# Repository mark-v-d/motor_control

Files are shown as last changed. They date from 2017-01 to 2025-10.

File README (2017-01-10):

Work in progress.

Servo motor controller. Currently supporting Mitsubishi HC-PQ[23]4,
HC-MFS13 and motors with a Hiperface encoder. Communication with ethernet
and the controller is intended to be used with linuxcnc.

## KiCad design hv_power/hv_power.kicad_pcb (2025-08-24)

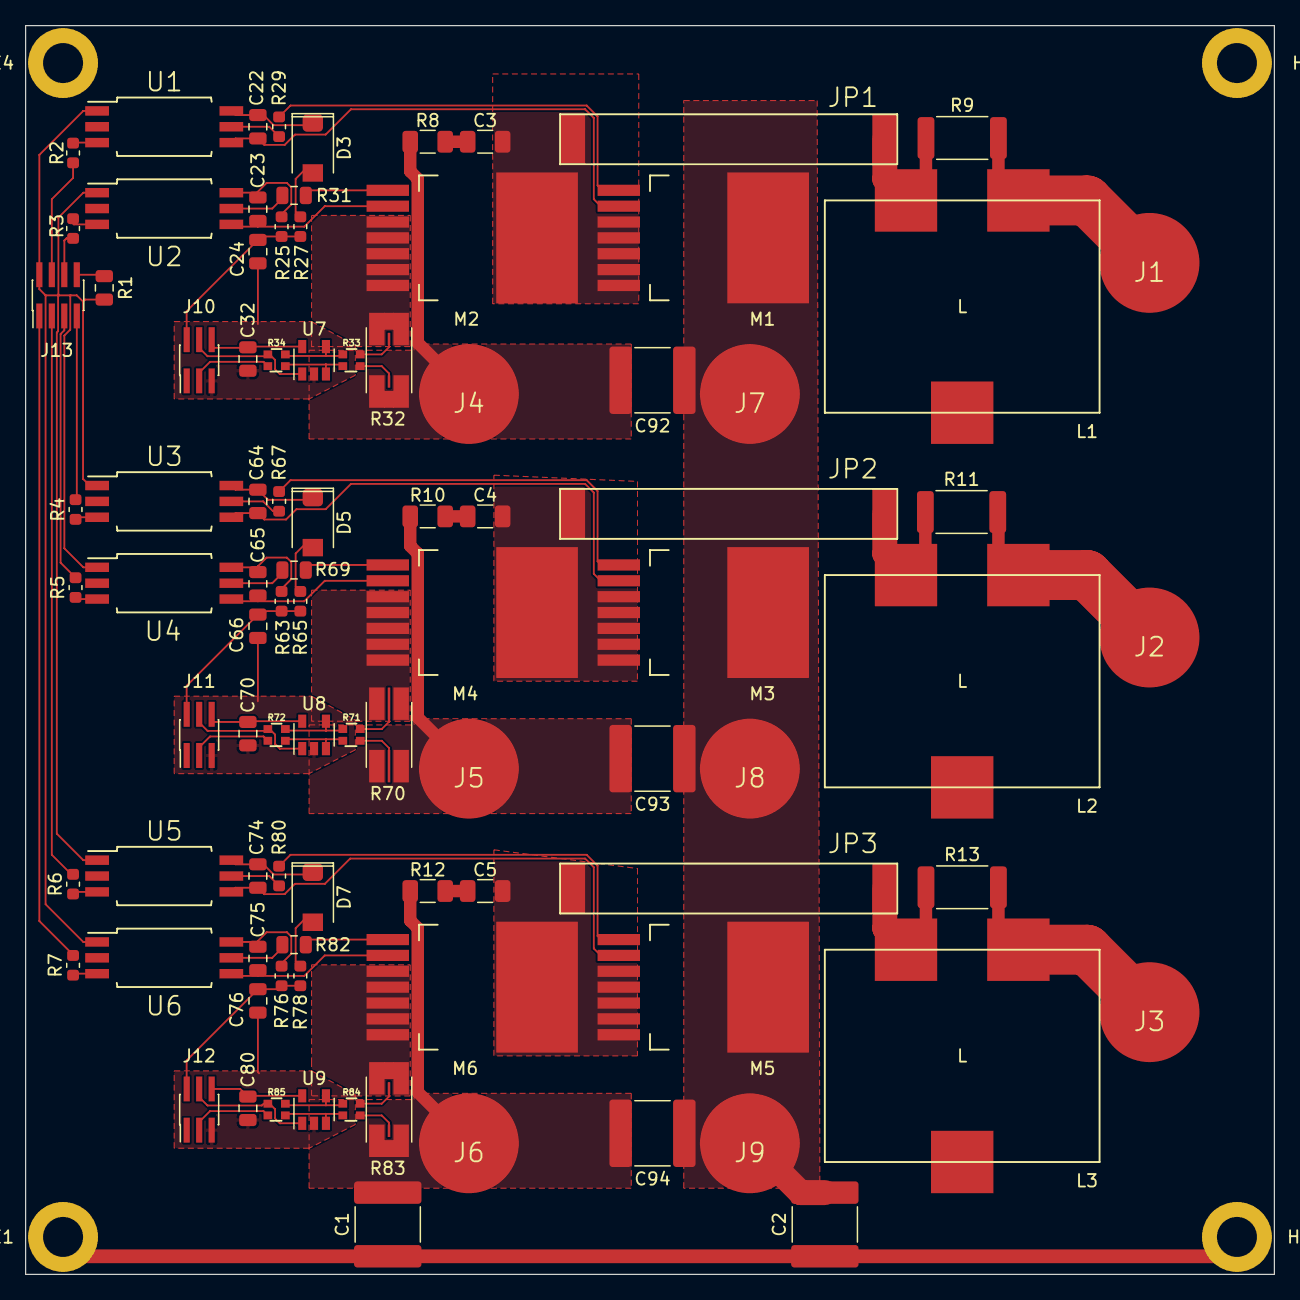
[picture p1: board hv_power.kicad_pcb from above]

Board: 2 copper layers, 100.0 x 100.0 mm, 95 parts (0 on the bottom side), 88 nets.

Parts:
C1, C2: 3.3nF; C_2220_5650Metric
C3, C4, C5: C; C_1206_3216Metric
C22, C23, C24, C64, C65, C66, C74, C75, C76: 1uF; C_0805_2012Metric
C32, C70, C80: 100nF; C_0805_2012Metric
C92, C93, C94: 100nF; C_2220_5650Metric
D3, D5, D7: STTH112A; D_SMA
HOLE1, HOLE4: HOLE; MountingHole_3.2mm_M3_DIN965_Pad
HOLE2, HOLE3: HOLE; MountingHole_3.2mm_M3_DIN965_Pad_ScreenAlignment
J1, J2, J3: Conn_01x01_Male; Wurth_7466204
J4, J5, J6: V-; Wurth_7466204
J7, J8, J9: V+; Wurth_7466204
J10, J11, J12: Conn_02x03_Odd_Even; PinHeader_2x03_P1.00mm_Vertical_SMD
J13: Conn_02x04_Odd_Even; PinHeader_2x04_P1.00mm_Vertical_SMD
JP1, JP2, JP3: Jumper_2_Bridged; jumper_3x25mm
L1, L2, L3: L; WE-HCF2013
M1, M2, M3, M4, M5, M6: TBD; TO-263-7-GDSKS_novias
R1: NTC; R_0805_2012Metric
R2, R3, R4, R5, R6, R7: 270; R_0603_1608Metric
R8, R10, R12: R; R_1206_3216Metric
R9, R11, R13: 270; R_2512_6332Metric
R25, R27, R29, R63, R65, R67, R76, R78, R80: 4.7; R_0603_1608Metric
R31, R69, R82: 4.7; R_0805_2012Metric
R32, R70, R83: R_Shunt; R_2512_Shunt_Rohm_PMR100_3.0m
R33, R71, R84: 100; ACASN
R34, R72, R85: 2k; ACASN
U1, U2, U3, U4, U5, U6: UCC23511DWY; SOIC-6_7.5x4.68mm_P1.27mm
U7, U8, U9: TSV991ILT; SOT-23-5

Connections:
+3.3V: J13.2, R1.1, U1.1 (anode), U2.1 (anode), U3.1 (anode), U4.1 (anode), U5.1 (anode), U6.1 (anode)
+800V: C2.2, C92.1, C93.1, C94.1, J7.1, J8.1, J9.1, M1.D, M3.D, M5.D
/HBH0: J13.4, R2.2
/HBH1: J13.7, R4.2
/HBH2: J13.3, R6.2
/HBL0: J13.6, R3.2
/HBL1: J13.5, R5.2
/HBL2: J13.1, R7.2
/H_Bridge0/0: C24.1, C32.2, J10.5, U7.2 (V-)
/H_Bridge0/+3.3: C32.1, J10.6, U7.5 (V+)
/H_Bridge0/+12: C24.2, J10.2, R25.2, R27.1
/H_Bridge0/CS: M2.S, R32.1
/H_Bridge0/C_N: J10.4, R34.1, U7.1
/H_Bridge0/C_P: J10.3, R34.2
/H_Bridge0/I_N: R33.1, R34.4, U7.4 (-)
/H_Bridge0/I_P: R33.2, R34.3, U7.3 (+)
/H_Bridge0/V-: C92.2, J4.1, R8.2, R32.4
/H_Bridge0/d1: R2.1, U1.3 (cathode)
/H_Bridge0/d2: R3.1, U2.3 (cathode)
/H_Bridge0/sw: C3.1, JP1.1 (A), M1.S, M2.D
/H_Bridge0/sw_+: C22.1, D3.C, U1.6 (vcc)
/H_Bridge0/sw_g: M1.G, R29.1
/H_Bridge0/sw_m1: JP1.2 (B), L1.2, R9.1
/H_Bridge0/sw_m2: J1.1, L1.1, R9.2
/H_Bridge0/sw_o: R29.2, U1.5 (out)
/H_Bridge0/sw_s: C22.2, M1.KS (ks), U1.4 (gnd)
/H_Bridge0/x: C3.2, R8.1
/H_Bridge1/0: C66.1, C70.2, J11.5, U8.2 (V-)
/H_Bridge1/+3.3: C70.1, J11.6, U8.5 (V+)
/H_Bridge1/+12: C66.2, J11.2, R63.2, R65.1
/H_Bridge1/CS: M4.S, R70.1
/H_Bridge1/C_N: J11.4, R72.1, U8.1
/H_Bridge1/C_P: J11.3, R72.2
/H_Bridge1/I_N: R71.1, R72.4, U8.4 (-)
/H_Bridge1/I_P: R71.2, R72.3, U8.3 (+)
/H_Bridge1/V-: C93.2, J5.1, R10.2, R70.4
/H_Bridge1/d1: R4.1, U3.3 (cathode)
/H_Bridge1/d2: R5.1, U4.3 (cathode)
/H_Bridge1/sw: C4.1, JP2.1 (A), M3.S, M4.D
/H_Bridge1/sw_+: C64.1, D5.C, U3.6 (vcc)
/H_Bridge1/sw_g: M3.G, R67.1
/H_Bridge1/sw_m1: JP2.2 (B), L2.2, R11.1
/H_Bridge1/sw_m2: J2.1, L2.1, R11.2
/H_Bridge1/sw_o: R67.2, U3.5 (out)
/H_Bridge1/sw_s: C64.2, M3.KS (ks), U3.4 (gnd)
/H_Bridge1/x: C4.2, R10.1
/H_Bridge2/0: C76.1, C80.2, J12.5, U9.2 (V-)
/H_Bridge2/+3.3: C80.1, J12.6, U9.5 (V+)
/H_Bridge2/+12: C76.2, J12.2, R76.2, R78.1
/H_Bridge2/CS: M6.S, R83.1
/H_Bridge2/C_N: J12.4, R85.1, U9.1
/H_Bridge2/C_P: J12.3, R85.2
/H_Bridge2/I_N: R84.1, R85.4, U9.4 (-)
/H_Bridge2/I_P: R84.2, R85.3, U9.3 (+)
/H_Bridge2/V-: C1.2, C94.2, J6.1, R12.2, R83.4
/H_Bridge2/d1: R6.1, U5.3 (cathode)
/H_Bridge2/d2: R7.1, U6.3 (cathode)
/H_Bridge2/sw: C5.1, JP3.1 (A), M5.S, M6.D
/H_Bridge2/sw_+: C74.1, D7.C, U5.6 (vcc)
/H_Bridge2/sw_g: M5.G, R80.1
/H_Bridge2/sw_m1: JP3.2 (B), L3.2, R13.1
/H_Bridge2/sw_m2: J3.1, L3.1, R13.2
/H_Bridge2/sw_o: R80.2, U5.5 (out)
/H_Bridge2/sw_s: C74.2, M5.KS (ks), U5.4 (gnd)
/H_Bridge2/x: C5.2, R12.1
/ntc: J13.8, R1.2
/pe: C1.1, C2.1, HOLE1.1, HOLE2.1
unnamed: D3.A, R27.2
unnamed: D5.A, R65.2
unnamed: D7.A, R78.2
unnamed: M2.G, R31.1
unnamed: C23.2, M2.KS (ks), U2.4 (gnd)
unnamed: M4.G, R69.1
unnamed: C65.2, M4.KS (ks), U4.4 (gnd)
unnamed: M6.G, R82.1
unnamed: C75.2, M6.KS (ks), U6.4 (gnd)
unnamed: R32.2, R33.4
unnamed: R32.3, R33.3
unnamed: R70.2, R71.4
unnamed: R70.3, R71.3
unnamed: R83.2, R84.4
unnamed: R83.3, R84.3
unnamed: R31.2, U2.5 (out)
unnamed: C23.1, R25.1, U2.6 (vcc)
unnamed: R69.2, U4.5 (out)
unnamed: C65.1, R63.1, U4.6 (vcc)
unnamed: R82.2, U6.5 (out)
unnamed: C75.1, R76.1, U6.6 (vcc)

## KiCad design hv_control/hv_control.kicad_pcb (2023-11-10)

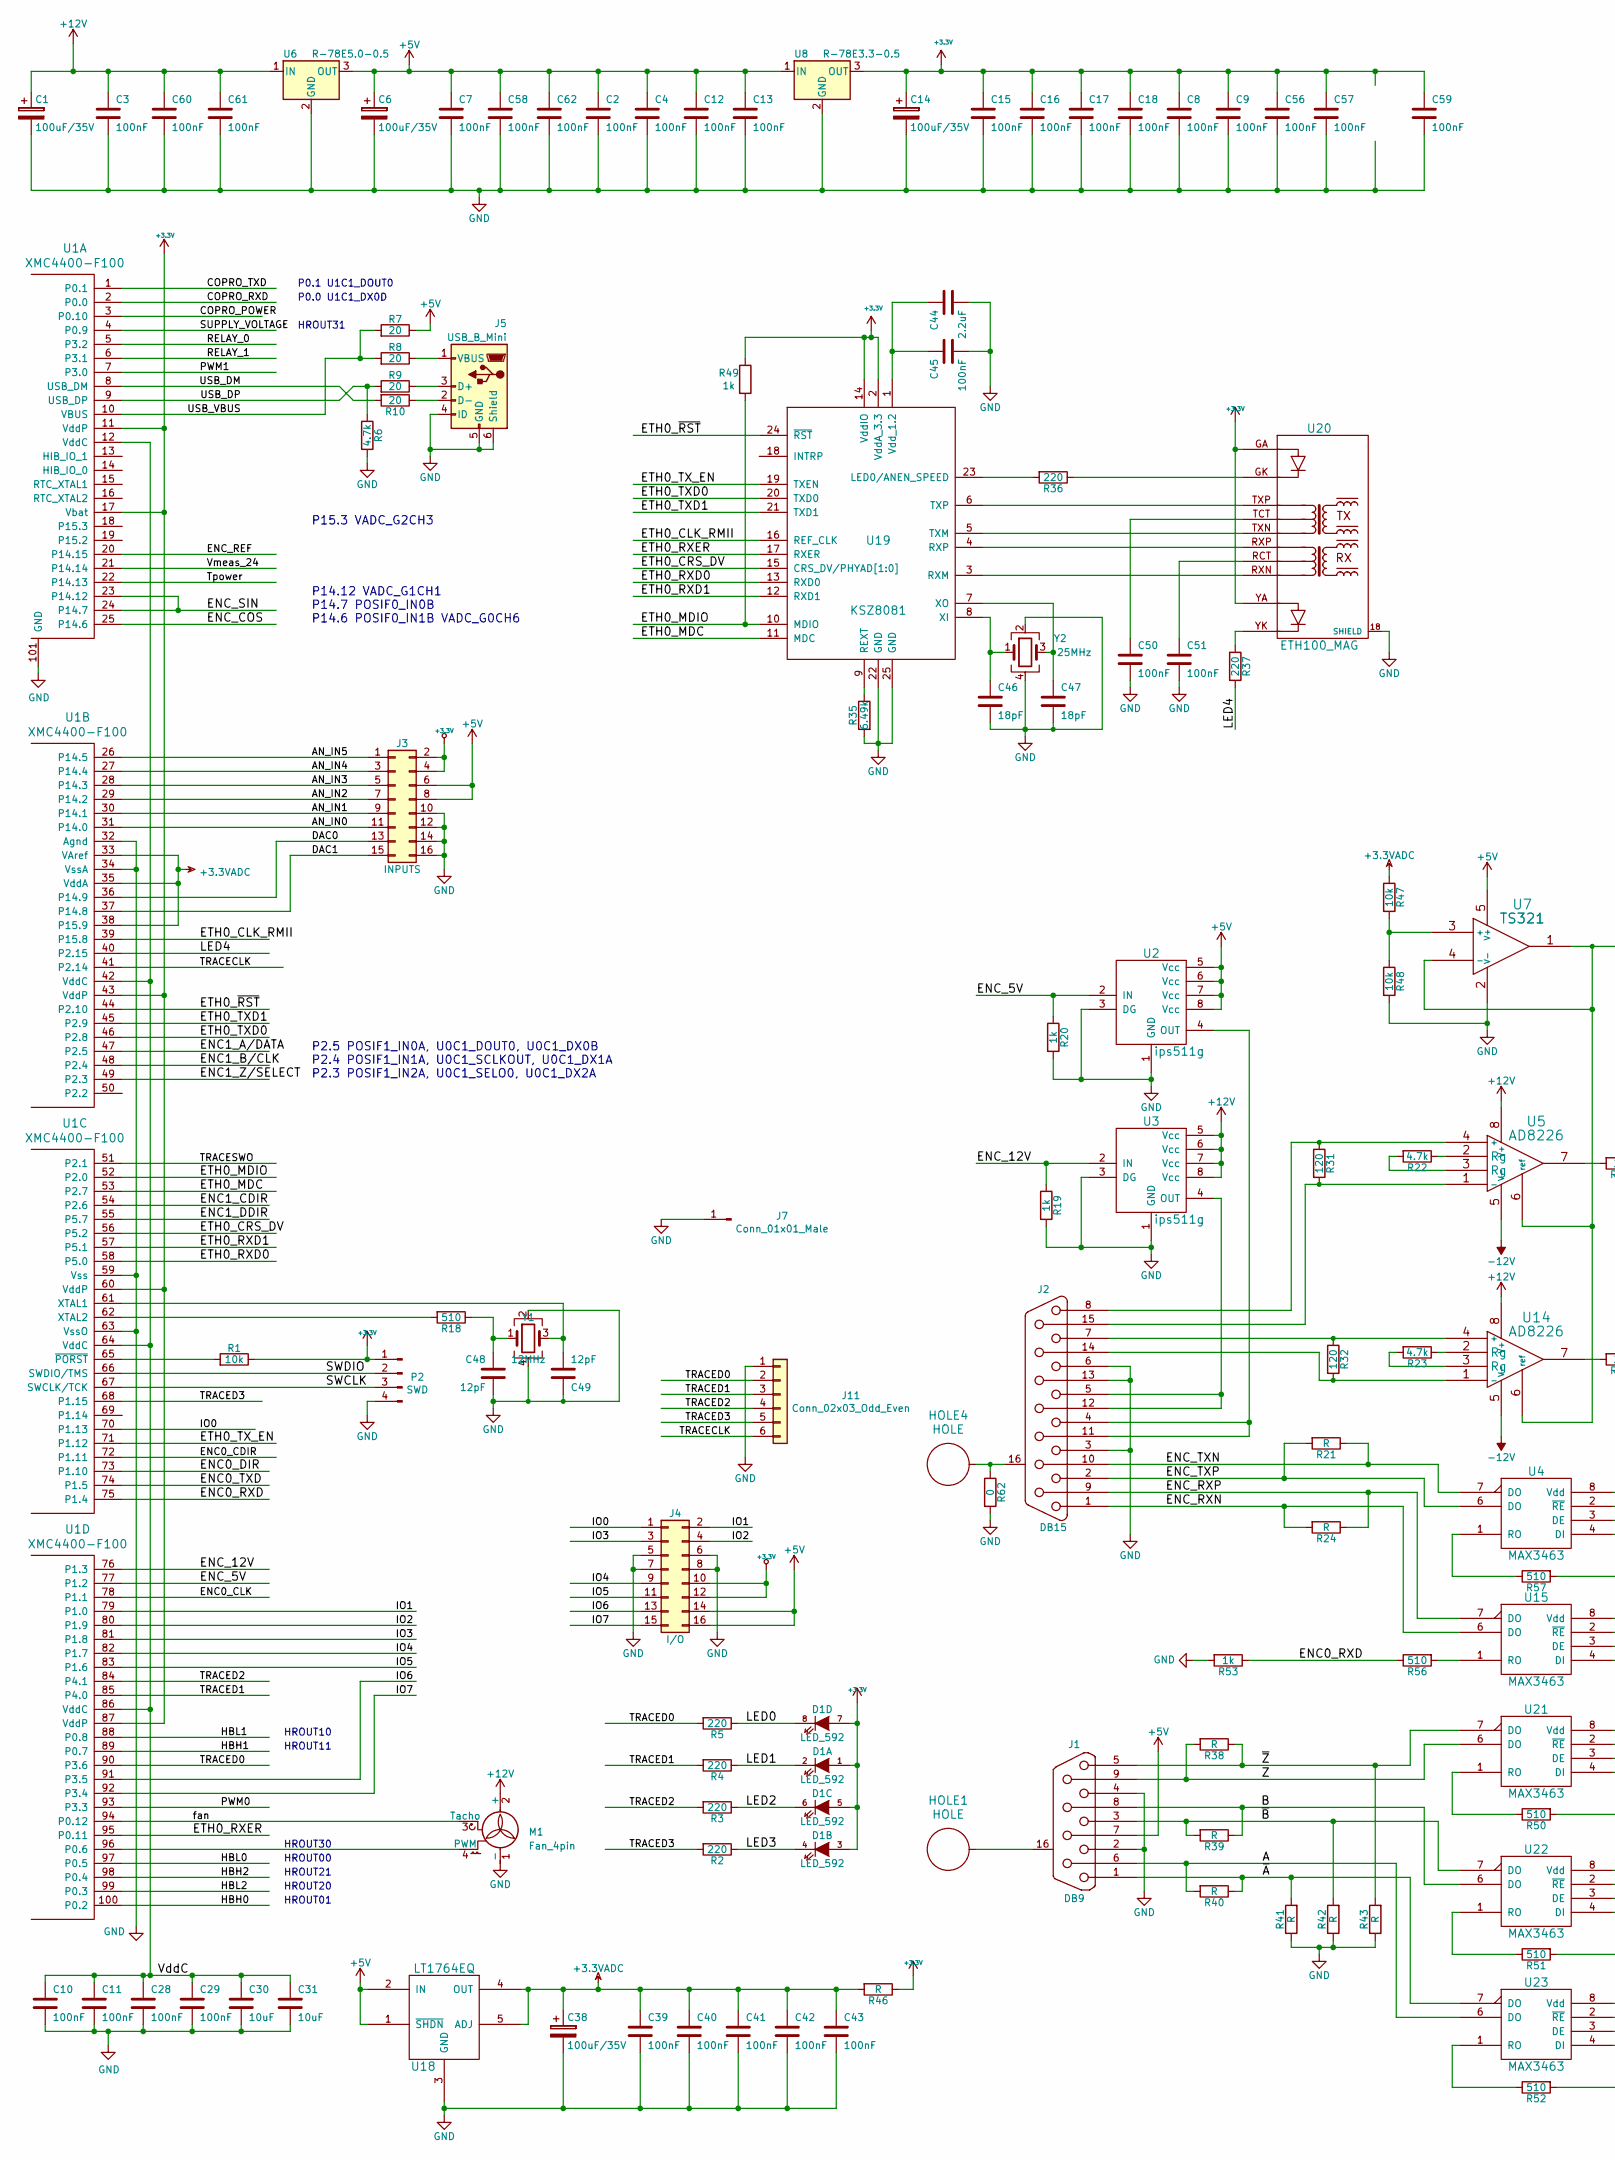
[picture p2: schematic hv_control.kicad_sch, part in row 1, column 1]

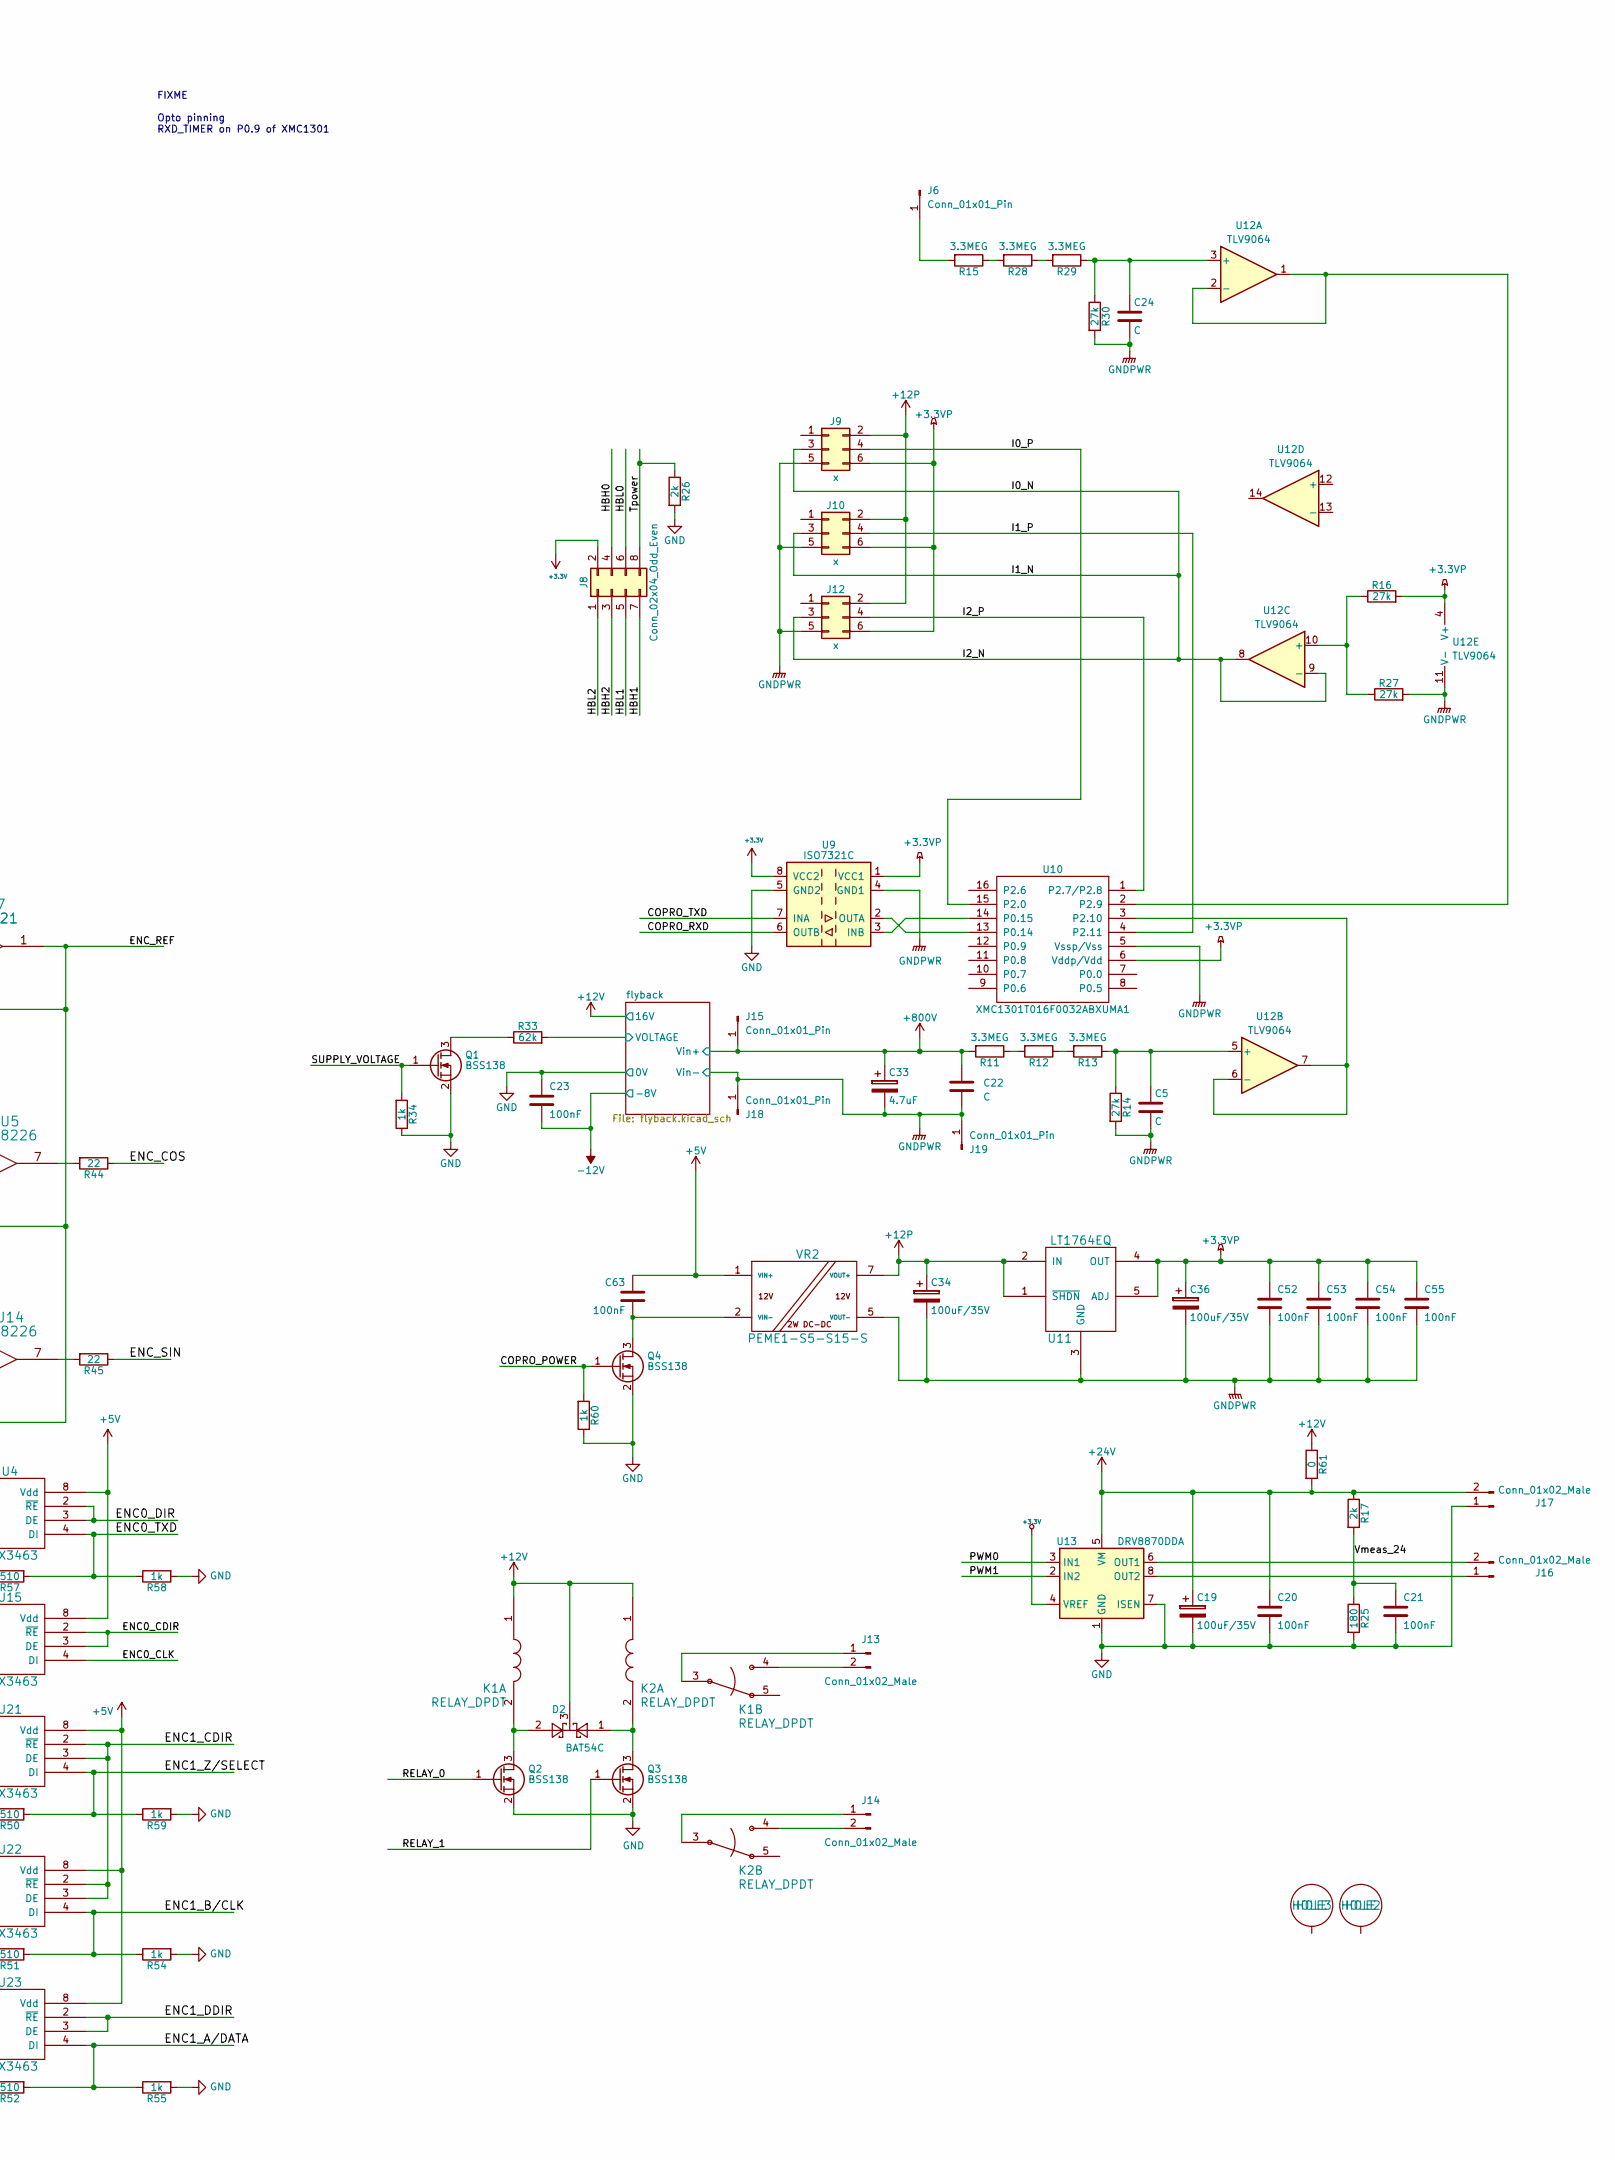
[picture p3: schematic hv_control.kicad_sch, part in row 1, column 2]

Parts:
C1, C6, C14, C19, C34, C36, C38: 100uF/35V; CP_Elec_8x10.5
C2, C3, C4, C7, C8, C9, C10, C11, C12, C13, C15, C16, C17, C18, C20, C21, C23, C28, C29, C39, C40, C41, C42, C43, C45, C50, C51, C52, C54, C55, C56, C57, C58, C59, C60, C61, C62, C63: 100nF; C_0603_1608Metric
C5, C24: C; C_0603_1608Metric
C22: C; C_Rect_L18.0mm_W6.0mm_P15.00mm_FKS3_FKP3
C30, C31: 10uF; C_1210_3225Metric
C33: 4.7uF; CP_Elec_10x14.3; PartNr EEVEB2G4R7Q
C44: 2.2uF; C_1206_3216Metric
C46, C47: 18pF; C_0603_1608Metric
C48, C49: 12pF; C_0603_1608Metric
C53: 100nF; C_0805_2012Metric
D1: LED_592; LED_592-3030-013F
D2: BAT54C; SOT-23
HOLE1, HOLE2: HOLE; MountingHole_3.2mm_M3_DIN965_Pad_ScreenAlignment
HOLE3, HOLE4: HOLE; MountingHole_3.2mm_M3_DIN965_Pad
J1: DB9; DB9F_ebay; PartNr 1734354-1; Farnell 1653978
J2: DB15; DB15F_ebay; PartNr 1-106506-2; Farnell 3417207
J3: INPUTS; PinHeader_2x08_P2.54mm_Vertical
J4: I/O; PinHeader_2x08_P2.54mm_Vertical
J5: USB_B_Mini; USB_Micro-B_Molex-105017-0001
J6, J15, J18, J19: Conn_01x01_Pin; Pin_D1.4mm_L8.5mm_W2.8mm_FlatFork
J7: Conn_01x01_Male; PinHeader_1x01_P2.54mm_Vertical
J8: Conn_02x04_Odd_Even; PinSocket_2x04_P1.00mm_Vertical_SMD; PartNr CLM-104-02-F-D; Digikey SAM15174-ND
J9, J10, J12: x; PinSocket_2x03_P1.00mm_Vertical_SMD; PartNr CLM-103-02-F-D; Digikey SAM12591-ND
J11: Conn_02x03_Odd_Even; PinHeader_1x06_P2.54mm_Vertical
J13, J14, J16, J17: Conn_01x02_Male; pin_2_5mm
K1, K2: RELAY_DPDT; T77
M1: Fan_4pin; FanPinHeader_1x04_P2.54mm_Vertical; PartNr 47053-3000; Mouser 538-47053-3000
P2: SWD; PinHeader_1x04_P2.54mm_Vertical
Q1, Q2, Q3, Q4: BSS138; SOT-23
R1, R47, R48: 10k; R_0603_1608Metric
R2, R3, R4, R5, R36, R37: 220; R_0603_1608Metric
R6, R22, R23: 4.7k; R_0603_1608Metric
R7: 20; R_0805_2012Metric
R8, R9, R10: 20; R_0603_1608Metric
R11, R12, R13, R15, R28, R29: 3.3MEG; R_1206_3216Metric
R14, R16, R27, R30: 27k; R_0603_1608Metric
R17, R26: 2k; R_0603_1608Metric
R18, R50, R51, R52, R56, R57: 510; R_0603_1608Metric
R19, R20, R34, R49, R53, R54, R55, R58, R59, R60: 1k; R_0603_1608Metric
R21, R24, R38, R39, R40, R41, R42, R43, R46: R; R_0603_1608Metric
R25: 180; R_0603_1608Metric
R31, R32: 120; R_0603_1608Metric
R33: 62k; R_0603_1608Metric
R35: 6.49k; R_0603_1608Metric
R44, R45: 22; R_0603_1608Metric
R61: 0; R_0805_2012Metric
R62: 0; R_0603_1608Metric
U1: XMC4400-F100; TQFP-100-1EP_14x14mm_P0.5mm_EP5x5mm; Farnell 2418735
U2, U3: ips511g; SOIC-8_3.9x4.9mm_P1.27mm
U4, U15, U21, U22, U23: MAX3463; SOIC-8_3.9x4.9mm_P1.27mm
U5, U14: AD8226; SOIC-8_3.9x4.9mm_P1.27mm; Farnell 1827360
U6: R-78E5.0-0.5; Converter_DCDC_RECOM_R-78E-0.5_THT
U7: TS321; SOT-23-5; PartNr TS321AILT; Farnell 1750165
U8: R-78E3.3-0.5; Converter_DCDC_RECOM_R-78E-0.5_THT
U9: ISO7321C; SOIC-8_3.9x4.9mm_P1.27mm; Digikey 296-42102-1-ND
U10: XMC1301T016F0032ABXUMA1; TSSOP-16_4.4x5mm_P0.65mm; Digikey XMC1301T016F0032ABXUMA1CT-ND
U11, U18: LT1764EQ; DD-PAK
U12: TLV9064; SOIC-14_3.9x8.7mm_P1.27mm
U13: DRV8870DDA; Texas_HTSOP-8-1EP_3.9x4.9mm_P1.27mm_EP2.95x4.9mm_Mask2.4x3.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; Digikey 296-42660-1-ND
U19: KSZ8081; QFN-24-1EP_4x4mm_P0.5mm_EP2.6x2.6mm; PartNr KSZ8081RNACA-TR; Farnell 2509802
U20: ETH100_MAG; PartNr SI-50170-F; Farnell 2676003
VR2: PEME1-S5-S15-S; RKZXXXXS; Digikey 102-6340-ND
Y1: 12MHz; Crystal_SMD_SeikoEpson_FA238-4Pin_3.2x2.5mm; PartNr QC3CA12.0000F12B23M; Farnell 2508630
Y2: 25MHz; Crystal_SMD_SeikoEpson_FA238-4Pin_3.2x2.5mm; PartNr QC3CA25.0000F18B23M; Farnell 2508942

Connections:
+3.3V: C8.1, C9.1, C14.1, C15.1, C16.1, C17.1, C18.1, C56.1, C57.1, C59.1, D1.1 (A), D1.3 (A), D1.5 (A), D1.7 (A), J3.2, J3.4, J4.10, J4.12, J8.2, P2.1, R1.1, R46.1, R49.1, U1.11 (VddP), U1.17 (Vbat), U1.43 (VddP), U1.60 (VddP), U1.87 (VddP), U8.3 (OUT), U9.8 (VCC2), U13.4 (VREF), U19.2 (VddA_3.3), U19.14 (VddIO), U20.GA, U20.YA
+3.3VADC: C38.1, C39.1, C40.1, C41.1, C42.1, C43.1, R46.2, R47.1, U1.33 (VAref), U1.35 (VddA), U1.38 (P15.9), U18.4 (OUT), U18.5 (ADJ)
+3.3VP: C36.1, C52.1, C53.1, C54.1, C55.1, J9.6, J10.6, J12.6, R16.2, U9.1 (VCC1), U10.6 (Vddp/Vdd), U11.4 (OUT), U11.5 (ADJ), U12.4 (V+)
+5V: C2.1, C4.1, C6.1, C7.1, C12.1, C13.1, C58.1, C62.1, C63.1, J1.7, J3.6, J3.8, J4.14, J4.16, R7.1, U2.5 (Vcc), U2.6 (Vcc), U2.7 (Vcc), U2.8 (Vcc), U4.8 (Vdd), U6.3 (OUT), U7.5 (V+), U8.1 (IN), U15.8 (Vdd), U18.1 (~SHDN), U18.2 (IN), U21.8 (Vdd), U22.8 (Vdd), U23.8 (Vdd), VR2.1 (VIN+)
+12P: C34.1, J9.2, J10.2, J12.2, U11.1 (~SHDN), U11.2 (IN), VR2.7 (VOUT+)
+24V: C19.1, C20.1, J17.2, R17.1, R61.2, U13.5 (VM)
+800V: C22.1, J15.1, R11.2; also elsewhere on the board
-12V: C23.2, U5.5 (V-), U14.5 (V-); also elsewhere on the board
/A: J1.6, R40.2, U23.6 (DO)
/AN_IN0: J3.11, U1.31 (P14.0)
/AN_IN1: J3.9, U1.30 (P14.1)
/AN_IN2: J3.7, U1.29 (P14.2)
/AN_IN3: J3.5, U1.28 (P14.3)
/AN_IN4: J3.3, U1.27 (P14.4)
/AN_IN5: J3.1, U1.26 (P14.5)
/B: J1.8, R39.1, U22.6 (DO)
/COPRO_POWER: Q4.1 (G), R60.2, U1.3 (P0.10)
/COPRO_RXD: U1.2 (P0.0), U9.6 (OUTB)
/COPRO_TXD: U1.1 (P0.1), U9.7 (INA)
/DAC0: J3.13, U1.36 (P14.9)
/DAC1: J3.15, U1.37 (P14.8)
/ENC0_CDIR: U1.72 (P1.11), U15.2 (~RE), U15.3 (DE)
/ENC0_CLK: U1.78 (P1.1), U15.4 (DI)
/ENC0_DIR: U1.73 (P1.10), U4.2 (~RE), U4.3 (DE)
/ENC0_RXD: R53.1, R56.1, U1.75 (P1.4)
/ENC0_TXD: R57.2, R58.1, U1.74 (P1.5), U4.4 (DI)
/ENC1_A/DATA: R52.2, R55.1, U1.47 (P2.5), U23.4 (DI)
/ENC1_B/CLK: R51.2, R54.1, U1.48 (P2.4), U22.4 (DI)
/ENC1_CDIR: U1.54 (P2.6), U21.2 (~RE), U21.3 (DE), U22.2 (~RE), U22.3 (DE)
/ENC1_DDIR: U1.55 (P5.7), U23.2 (~RE), U23.3 (DE)
/ENC1_Z/SELECT: R50.2, R59.1, U1.49 (P2.3), U21.4 (DI)
/ENC_5V: R20.1, U1.77 (P1.2), U2.2 (IN)
/ENC_12V: R19.1, U1.76 (P1.3), U3.2 (IN)
/ENC_COS: R44.1, U1.25 (P14.6)
/ENC_REF: U1.20 (P14.15), U5.6 (ref), U7.1, U7.4 (-), U14.6 (ref)
/ENC_RXN: J2.1, R24.2, U15.6 (DO)
/ENC_RXP: J2.9, R24.1, U15.7 (DO)
/ENC_SIN: R45.1, U1.23 (P14.12), U1.24 (P14.7)
/ENC_TXN: J2.10, R21.1, U4.7 (DO)
/ENC_TXP: J2.2, R21.2, U4.6 (DO)
/ETH0_CLK_RMII: U1.39 (P15.8), U19.16 (REF_CLK)
/ETH0_CRS_DV: U1.56 (P5.2), U19.15 (CRS_DV/PHYAD[1:0])
/ETH0_MDC: U1.53 (P2.7), U19.11 (MDC)
/ETH0_MDIO: R49.2, U1.52 (P2.0), U19.10 (MDIO)
/ETH0_RXD0: U1.58 (P5.0), U19.13 (RXD0)
/ETH0_RXD1: U1.57 (P5.1), U19.12 (RXD1)
/ETH0_RXER: U1.95 (P0.11), U19.17 (RXER)
/ETH0_TXD0: U1.46 (P2.8), U19.20 (TXD0)
/ETH0_TXD1: U1.45 (P2.9), U19.21 (TXD1)
/ETH0_TX_EN: U1.71 (P1.12), U19.19 (TXEN)
/ETH0_~RST: U1.44 (P2.10), U19.24 (~RST)
/HBH0: J8.4, U1.100 (P0.2)
/HBH1: J8.7, U1.89 (P0.7)
/HBH2: J8.3, U1.98 (P0.4)
/HBL0: J8.6, U1.97 (P0.5)
/HBL1: J8.5, U1.88 (P0.8)
/HBL2: J8.1, U1.99 (P0.3)
/I0_N: J9.3, J10.3, J12.3, U12.8, U12.9 (-)
/I0_P: J9.4, U10.15 (P2.0)
/I1_P: J10.4, U10.4 (P2.11)
/I2_P: J12.4, U10.1 (P2.7/P2.8)
/IO0: J4.1, U1.70 (P1.13)
/IO1: J4.2, U1.79 (P1.0)
/IO2: J4.4, U1.80 (P1.9)
/IO3: J4.3, U1.81 (P1.8)
/IO4: J4.9, U1.82 (P1.7)
/IO5: J4.11, U1.83 (P1.6)
/IO6: J4.13, U1.91 (P3.5)
/IO7: J4.15, U1.92 (P3.4)
/LED0: D1.8 (K), R5.1
/LED1: D1.2 (K), R4.1
/LED2: D1.6 (K), R3.1
/LED3: D1.4 (K), R2.1
/LED4: R37.1, U1.40 (P2.15)
/PWM0: U1.93 (P3.3), U13.3 (IN1)
/PWM1: U1.7 (P3.0), U13.2 (IN2)
/RELAY_0: Q2.1 (G), U1.5 (P3.2)
/RELAY_1: Q3.1 (G), U1.6 (P3.1)
/SWCLK: P2.3, U1.67 (SWCLK/TCK)
/SWDIO: P2.2, U1.66 (SWDIO/TMS)
/TRACECLK: J11.6, U1.41 (P2.14)
/TRACED0: J11.2, R5.2, U1.90 (P3.6)
/TRACED1: J11.3, R4.2, U1.85 (P4.0)
/TRACED2: J11.4, R3.2, U1.84 (P4.1)
/TRACED3: J11.5, R2.2, U1.68 (P1.15)
/TRACESWO: U1.51 (P2.1)
/Tpower: J8.8, R26.1, U1.22 (P14.13)
/USB_DM: R10.2, U1.8 (USB_DM)
/USB_DP: R6.1, R9.2, U1.9 (USB_DP)
/USB_VBUS: R7.2, R8.2, U1.10 (VBUS)
/VddC: C10.1, C11.1, C28.1, C29.1, C30.1, C31.1, U1.12 (VddC), U1.42 (VddC), U1.64 (VddC), U1.86 (VddC)
/Vmeas_24: C21.1, R17.2, R25.1, U1.21 (P14.14)
/Z: J1.9, R38.2, U21.6 (DO)
/fan: M1.3 (Tacho), U1.94 (P0.12)
/flyback/VOLTAGE: R33.2; also elsewhere on the board
/~A: J1.1, R40.1, R41.2, U23.7 (DO)
/~B: J1.3, R39.2, R42.2, U22.7 (DO)
/~Z: J1.5, R38.1, R43.2, U21.7 (DO)
GNDPWR: C5.2, C22.2, C24.2, C34.2, C36.2, C52.2, C53.2, C54.2, C55.2, J9.5, J10.5, J12.5, J18.1, J19.1, R14.2, R27.2, R30.2, U9.4 (GND1), U10.5 (Vssp/Vss), U11.3 (GND), U12.11 (V-), VR2.5 (VOUT-); also elsewhere on the board
unnamed: C48.1, R18.1, Y1.1
unnamed: C50.1, U20.TCT
unnamed: C51.1, U20.RCT
unnamed: HOLE1.1, J1.16
unnamed: HOLE4.1, J2.16, R62.1
unnamed: J2.5, J2.12, U3.4 (OUT)
unnamed: J2.14, R32.2, U14.1 (-)
unnamed: J2.15, R31.2, U5.1 (-)
unnamed: J2.4, J2.11 (P111), U2.4 (OUT)
unnamed: J5.3 (D+), R9.1
unnamed: J5.2 (D-), R10.1
unnamed: J5.1 (VBUS), R8.1
unnamed: J6.1, R15.2
unnamed: J13.1, K1.3 (common)
unnamed: J13.2, K1.4 (break)
unnamed: J14.1, K2.3 (common)
unnamed: J14.2, K2.4 (break)
unnamed: J16.1, U13.8 (OUT2)
unnamed: J16.2, U13.6 (OUT1)
unnamed: D2.2, K1.2 (a2), Q2.3 (D)
unnamed: D2.1, K2.2 (a2), Q3.3 (D)
unnamed: M1.4 (PWM), U1.96 (P0.6)
unnamed: C63.2, Q4.3 (D), VR2.2 (VIN-)
unnamed: R11.1, R12.2
unnamed: R12.1, R13.2
unnamed: R15.1, R28.2
unnamed: R22.1, U5.2 (Rg)
unnamed: R22.2, U5.3 (Rg)
unnamed: R23.1, U14.2 (Rg)
unnamed: R23.2, U14.3 (Rg)
unnamed: R28.1, R29.2
unnamed: R36.1, U20.GK
unnamed: R37.2, U20.YK
unnamed: R44.2, U5.7
unnamed: R45.2, U14.7
unnamed: C49.2, U1.61 (XTAL1), Y1.3
unnamed: R18.2, U1.62 (XTAL2)
unnamed: R1.2, U1.65 (~PORST)
unnamed: R57.1, U4.1 (RO)
unnamed: J2.8, R31.1, U5.4 (+)
unnamed: R47.2, R48.1, U7.3 (+)
unnamed: U9.2 (OUTA), U10.13 (P0.14)
unnamed: U9.3 (INB), U10.14 (P0.15)
unnamed: U10.2 (P2.9), U12.1, U12.2 (-)
unnamed: U10.3 (P2.10), U12.6 (-), U12.7
unnamed: C24.1, R29.1, R30.1, U12.3 (+)
unnamed: C5.1, R13.1, R14.1, U12.5 (+)
unnamed: R16.1, R27.1, U12.10 (+)
unnamed: J2.7, R32.1, U14.4 (+)
unnamed: R56.2, U15.1 (RO)
unnamed: R36.2, U19.23 (LED0/ANEN_SPEED)
unnamed: R35.1, U19.9 (REXT)
unnamed: U19.3 (RXM), U20.RXN
unnamed: U19.4 (RXP), U20.RXP
unnamed: U19.5 (TXM), U20.TXN
unnamed: U19.6 (TXP), U20.TXP
unnamed: C44.1, C45.1, U19.1 (Vdd_1.2)
unnamed: C46.1, U19.8 (XI), Y2.1
unnamed: C47.1, U19.7 (XO), Y2.3
unnamed: R50.1, U21.1 (RO)
unnamed: R51.1, U22.1 (RO)
unnamed: R52.1, U23.1 (RO)

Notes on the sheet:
HROUT00
HROUT30
HROUT31
FIXME Opto pinning RXD_TIMER on P0.9 of XMC1301
HROUT10
HROUT01
P14.12 VADC_G1CH1 P14.7 POSIF0_IN0B P14.6 POSIF0_IN1B VADC_G0CH6
HROUT20
HROUT21
P15.3 VADC_G2CH3
HROUT11
P0.1 U1C1_DOUT0
P0.0 U1C1_DX0D
P2.5 POSIF1_IN0A, U0C1_DOUT0, U0C1_DX0B P2.4 POSIF1_IN1A, U0C1_SCLKOUT, U0C1_DX1A P2.3 POSIF1_IN2A, U0C1_SELO0, U0C1_DX2A

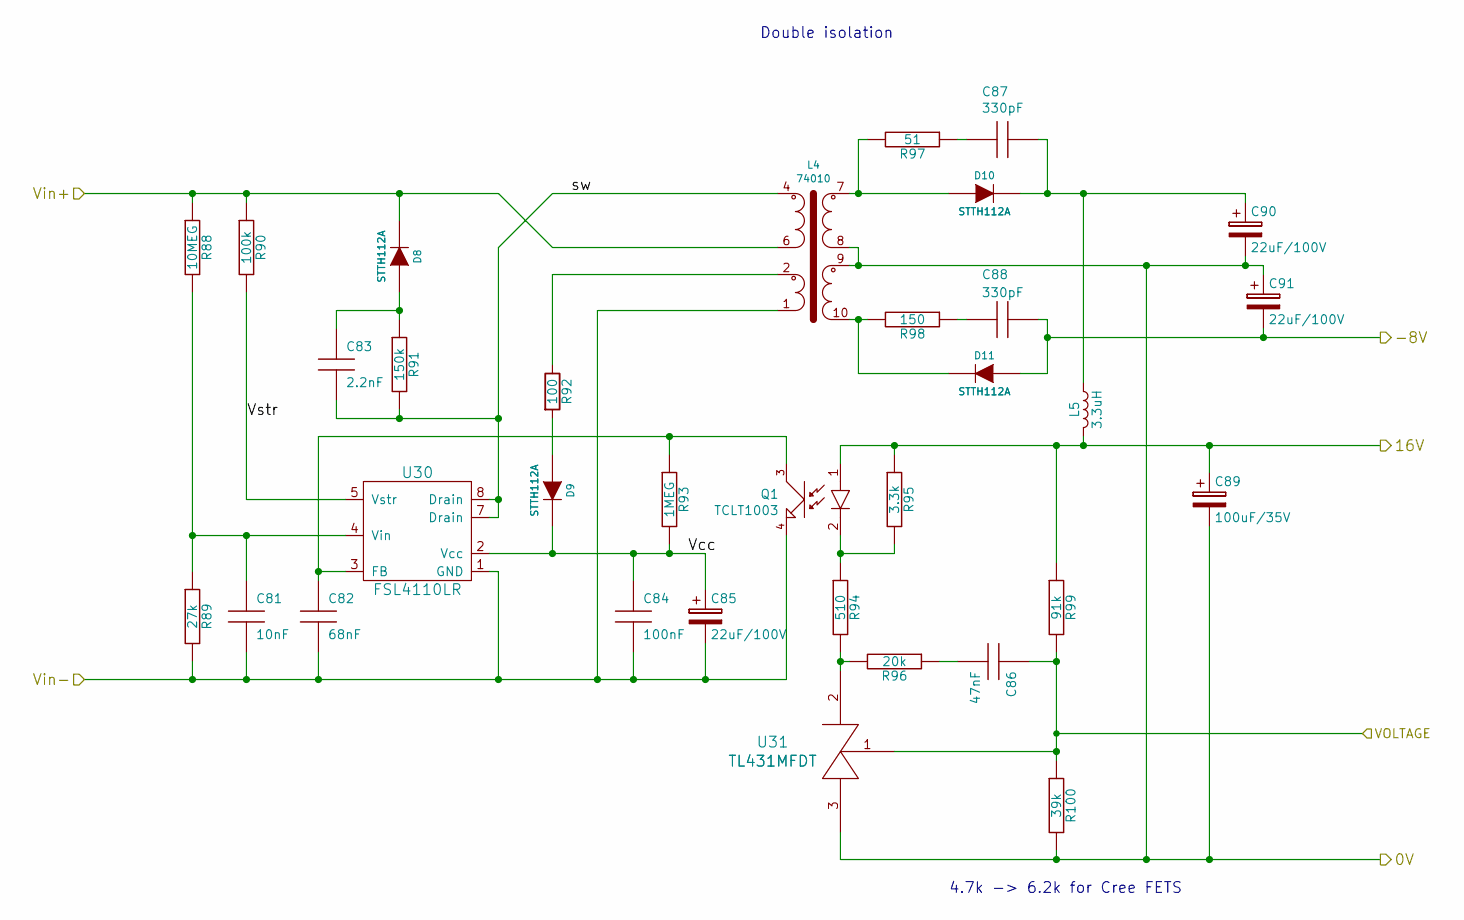
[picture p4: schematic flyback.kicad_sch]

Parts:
C81: 10nF; C_0603_1608Metric; Mouser 80-C0603C103K5REAUTO
C82: 68nF; C_0603_1608Metric
C83: 2.2nF; C_1206_3216Metric; PartNr 1206J1K00222KJT; Digikey 311-1511-1-ND
C84: 100nF; C_0603_1608Metric
C85, C90, C91: 22uF/100V; CP_Elec_8x10.5; PartNr EEE-1HA220WP; Mouser 667-EEE-1HA220WP
C86: 47nF; C_0603_1608Metric
C87, C88: 330pF; C_0603_1608Metric
C89: 100uF/35V; CP_Elec_8x10.5; PartNr EEE-1HA220WP; Mouser 667-EEE-1HA220WP
D8: STTH112A; D_SMA; PartNr STTH112A; Farnell 2341589
D9, D10, D11: STTH112A; D_SMA; PartNr STTH112A; Digikey 497-8048-1-ND
L4: 74010; Myrra_EE16; PartNr 74010; Farnell 1214645
L5: 3.3uH; L_Coilcraft_ME3220; PartNr ME3220-332MLB; Mouser 994-ME3220-332MLB
Q1: TCLT1003; SOP-4_3.8x7.5mm_P2.54mm; PartNr TCLT1003
R88: 10MEG; R_1206_3216Metric; Farnell 2470930
R89: 27k; R_0603_1608Metric
R90: 100k; R_1206_3216Metric; PartNr CHV1206-FX-1003ELF; Farnell 2470926
R91: 150k; R_2010_5025Metric; PartNr 3520150KJT; Digikey A102501CT-ND
R92: 100; R_0603_1608Metric
R93: 1MEG; R_0603_1608Metric
R94: 510; R_0603_1608Metric
R95: 3.3k; R_0603_1608Metric
R96: 20k; R_0603_1608Metric
R97: 51; R_0603_1608Metric
R98: 150; R_0603_1608Metric
R99: 91k; R_0603_1608Metric
R100: 39k; R_0603_1608Metric
U30: FSL4110LR; DIP-8-N6_W7.62mm; PartNr FSL4110LRN; Digikey FSL4110LRN-ND
U31: TL431MFDT; SOT-23; Farnell 2575136

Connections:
+800V: D8.C, L4.6, R88.1, R90.1; also elsewhere on the board
-12V: C88.1, C91.2, D11.A; also elsewhere on the board
/flyback/VOLTAGE: C86.1, R99.2, R100.1, U31.1 (ref); also elsewhere on the board
/flyback/Vcc: C84.1, C85.1, D9.C, R93.2, U30.2 (Vcc)
/flyback/Vstr: R90.2, U30.5 (Vstr)
/flyback/sw: C83.2, L4.4, R91.2, U30.7 (Drain), U30.8 (Drain)
GNDPWR: C81.2, C82.2, C84.2, C85.2, L4.1, Q1.4 (E), R89.2, U30.1 (GND); also elsewhere on the board
unnamed: C83.1, D8.A, R91.1
unnamed: C86.2, R96.1
unnamed: C87.1, C90.1, D10.C, L5.1
unnamed: C87.2, R97.1
unnamed: C88.2, R98.1
unnamed: D9.A, R92.2
unnamed: D10.A, L4.7, R97.2
unnamed: D11.C, L4.10, R98.2
unnamed: L4.2, R92.1
unnamed: C81.1, R88.2, R89.1, U30.4 (Vin)
unnamed: R94.2, R96.2, U31.2 (C)

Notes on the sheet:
Double isolation
4.7k -> 6.2k for Cree FETS

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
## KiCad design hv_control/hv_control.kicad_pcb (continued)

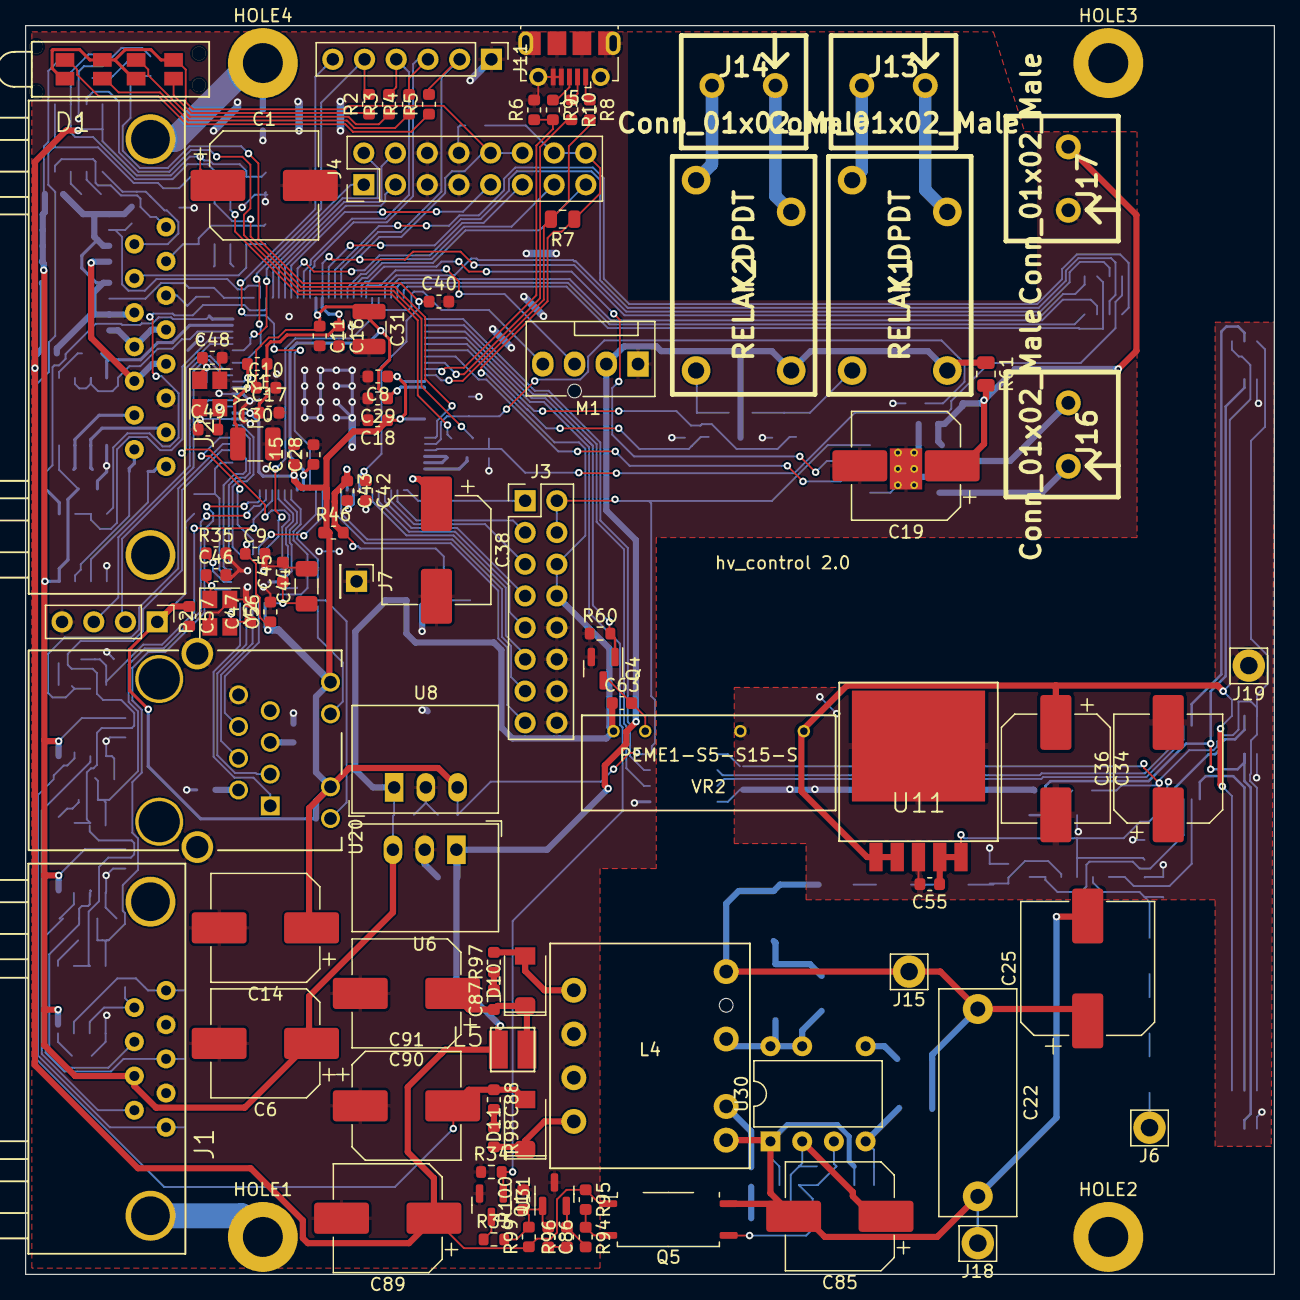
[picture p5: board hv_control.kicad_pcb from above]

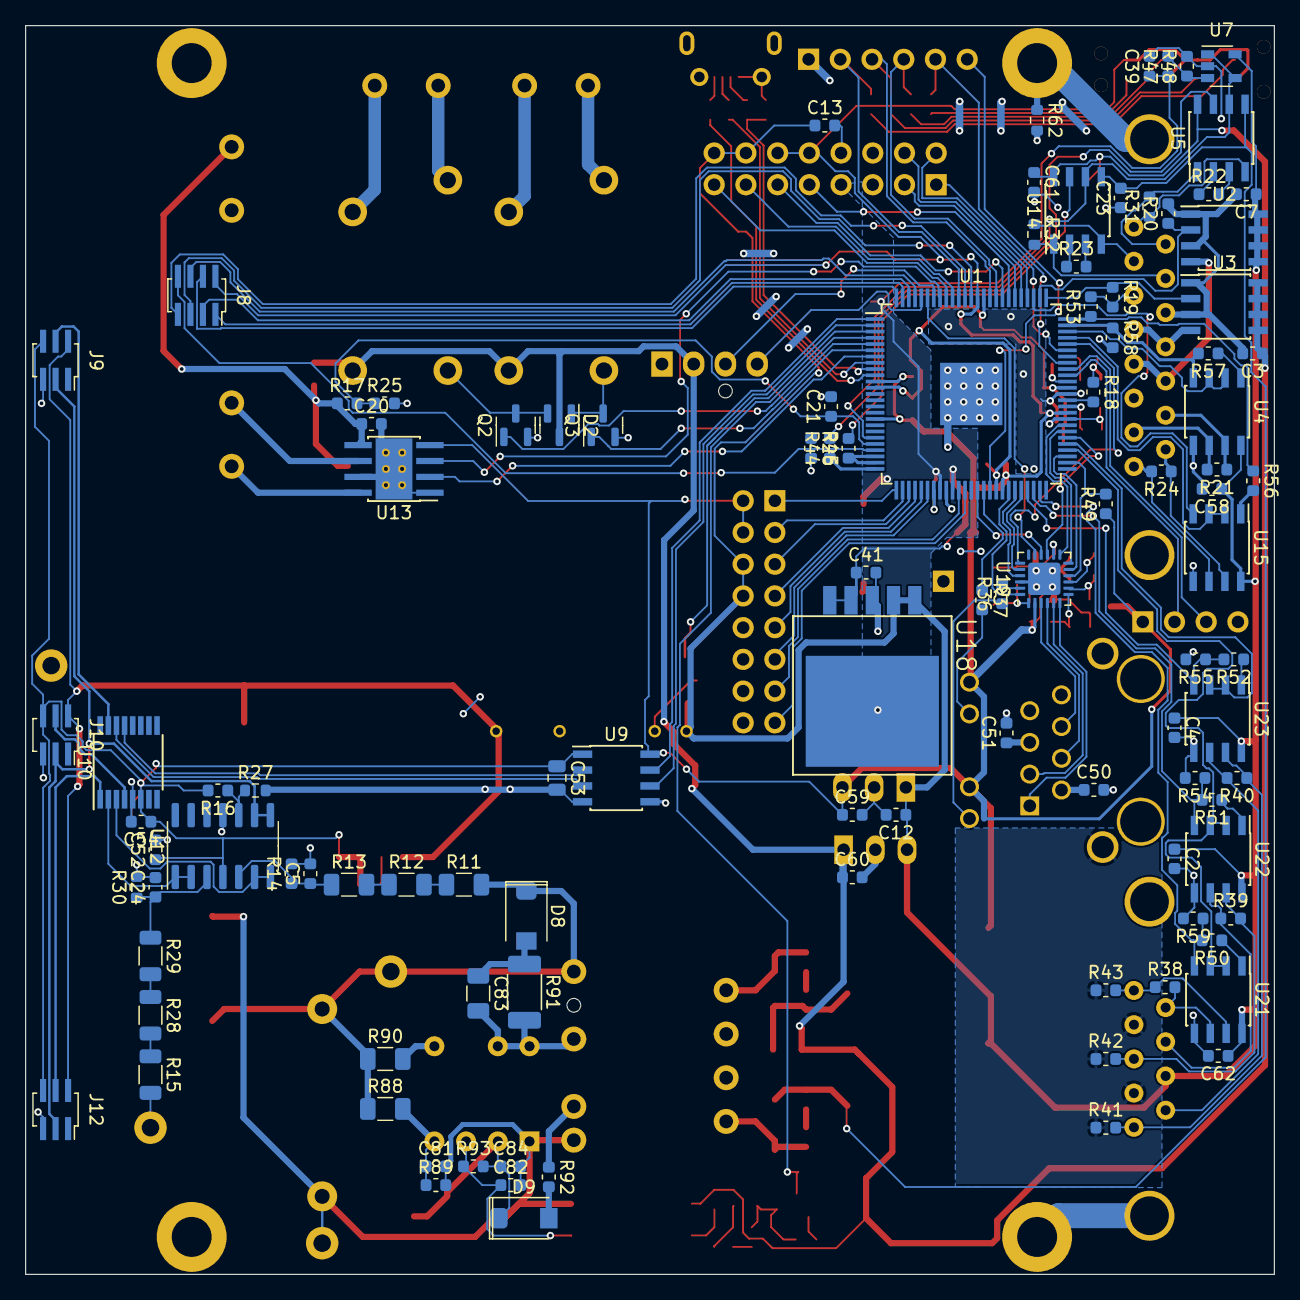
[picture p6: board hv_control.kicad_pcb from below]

Board: 2 copper layers, 100.0 x 100.0 mm, 209 parts (105 on the bottom side), 180 nets.

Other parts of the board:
C25: 4.7uF; CP_Elec_10x14.3
Q5: TCLT1003; SOP-4_3.8x7.5mm_P2.54mm

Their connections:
+800V: C25.1; also elsewhere on the board
GNDPWR: C25.2, Q5.4 (E); also elsewhere on the board

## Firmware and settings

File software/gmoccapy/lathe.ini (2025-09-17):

# EMC controller parameters for a simulated machine.
# General note: Comments can either be preceded with a # or ; - either is
# acceptable, although # is in keeping with most linux config files.

# General section -------------------------------------------------------------
[EMC]
VERSION = 1.1
MACHINE =               gmoccapy_lathe
#DEBUG =               0x7FFFFFFF
DEBUG = 0

# for details see nc_files/subroutines/maco_instructions.txt
[DISPLAY]
	DISPLAY = gmoccapy
	LATHE = 1
	BACK_TOOL_LATHE = 0
	EMBED_TAB_NAME = Spindle_load
	EMBED_TAB_LOCATION = box_custom_4
	EMBED_TAB_COMMAND = gladevcp -x {XID} -H spindle_load.hal spindle_load.glade 

	EMBED_TAB_NAME = Not_cool
	EMBED_TAB_LOCATION = box_cooling
	EMBED_TAB_COMMAND = hide
	EMBED_TAB_NAME = Drive_status
	EMBED_TAB_LOCATION = hbox_jog
	EMBED_TAB_COMMAND = gladevcp -x {XID} -H drive_status.hal drive_status.glade 

	# Cycle time, in milliseconds, that display will sleep between polls
	CYCLE_TIME =            100

	# Highest value that will be allowed for feed override, 1.0 = 100%
	MAX_FEED_OVERRIDE =     1.5
	MAX_SPINDLE_OVERRIDE =  1.2
	MIN_SPINDLE_OVERRIDE = .5

	# Prefix to be used
	PROGRAM_PREFIX = ~/nc_files/

	# Introductory graphic
	INTRO_GRAPHIC = 
	INTRO_TIME = 5

	# list of selectable jog increments
	INCREMENTS = 0.100 mm, 0.010 mm, 0.001 mm

[FILTER]
PROGRAM_EXTENSION = .png,.gif,.jpg Grayscale Depth Image
PROGRAM_EXTENSION = .py Python Script
png = image-to-gcode
gif = image-to-gcode
jpg = image-to-gcode
py = python3

[XHC_HB04_CONFIG]
	# specify layout = n for LIB:xhc-hb04-layout{n}.cfg files
	layout = 2
	# coords: specify upto 4 letters from set {x y z a b c u v w}
	# coords: switch labels are xyza but any unique 4 letters
	#         from the set {xyxabcuvw) can be used (if the coord exists)
	coords = x z
	# lowpass settings:
	# coef: slows rate of change of output,  range: 0 < coef < 1
	coefs = 1 1 1 1
	# scale plus or minus, rotaries may require larger scale factor:
	scales = -1 1 1 1
	# jogmode normal(default) or vnormal
	jogmode = normal
	# sequence 1: 0.001,0.010,0.100,1.000 (mm-based machine)
	# sequence 2: 0.001,0.005,0.010,0.020 (inch-based machine)
	# sequence 3: 0.001,0.010,0.100
	# sequence 4: 0.001,0.005,0.010,0.020,0.050,0.100
	# sequence 5: 0.001,0.010,0.050,0.100,1.000
	sequence = 1
	# require_pendant = yes|no: create xhc-hb04 hal pins when pendant not
	#                           connected at startup
	require_pendant = no
	# inch_or_mm = in | mm
	inch_or_mm = mm
	# mpg_accels: provision for reduced acceleration for manual mode jogging
	mpg_accels = 300 300 300 300

[APPLICATIONS]
	APP = monitor-xhc-hb04

# Task controller section -----------------------------------------------------
[RS274NGC]
RS274NGC_STARTUP_CODE = G18 G21 G40 G49 G54 G80 G90 G94 G7 M9 M5 G64 P0.005
PARAMETER_FILE = sim.var
SUBROUTINE_PATH = macros

# Motion control section ------------------------------------------------------
[EMCMOT]
EMCMOT =              motmod
COMM_TIMEOUT =          1.0
BASE_PERIOD  =          100000
SERVO_PERIOD =          1000000

# Hardware Abstraction Layer section --------------------------------------------------
[TASK]
TASK =                  milltask
CYCLE_TIME =            0.001

# Part program interpreter section --------------------------------------------
[HAL]
HALFILE = core_sim_lathe.hal
HALFILE = spindle_sim.hal
HALFILE = simulated_home_lathe.hal
HALFILE = LIB:xhc-hb04.tcl

# Single file that is executed after the GUI has started.
POSTGUI_HALFILE = gmoccapy_postgui.hal

HALUI = halui

# Trajectory planner section --------------------------------------------------
[HALUI]
# these are examples, edit as required:
# a halui hal pin is created for each MDI_COMMAND below
# halui.mdi-command-00, halui.mdi-command-01,... etc
# Gele knop, waypoint
MDI_COMMAND=#<waypoint_x>=#<_x>
# Macro-1
MDI_COMMAND=o<face> call
# Macro-2
MDI_COMMAND=o<simple_cycle> call [#<waypoint_x>] [#<waypoint_z>]
# Macro 3
MDI_COMMAND=(debug, example: mdi-03)
# mdi-04, Waypoint voor Z
MDI_COMMAND=#<waypoint_z>=#<_z>
MDI_COMMAND=(debug, example: mdi-05)
# Macro 6
MDI_COMMAND=(debug, example: mdi-06)
#Macro 7
MDI_COMMAND=(debug, example: mdi-07)
MDI_COMMAND=(debug, example: mdi-08)
MDI_COMMAND=(debug, example: mdi-09)
# Safe-z
MDI_COMMAND=(debug, example: mdi-10)
MDI_COMMAND=(debug, example: mdi-11)

MDI_COMMAND= G10 L20 P0 X0
MDI_COMMAND= G10 L20 P0 Y0
MDI_COMMAND= G10 L20 P0 Z0
MDI_COMMAND= G10 L20 P0 C0
#No Content

[TRAJ]
COORDINATES =      X Z
LINEAR_UNITS =     mm
ANGULAR_UNITS =    degree
DEFAULT_LINEAR_VELOCITY = 50
MAX_LINEAR_VELOCITY = 234
POSITION_FILE =    position.txt
#NO_FORCE_HOMING = 1

# First axis
[EMCIO]
EMCIO = 		io
CYCLE_TIME =    0.100

# tool table file
TOOL_TABLE = lathe.tbl

[KINS]
KINEMATICS = trivkins coordinates=XZ
JOINTS = 2

[AXIS_X]
MIN_LIMIT = -50.0
MAX_LIMIT = 200.0
MAX_VELOCITY = 166
MAX_ACCELERATION = 1500.0

[JOINT_0]
TYPE =                          LINEAR
MAX_VELOCITY =                  166
MAX_ACCELERATION =              1500.0
BACKLASH = 0.000
INPUT_SCALE =                   4000
OUTPUT_SCALE = 1.000
MIN_LIMIT =                     -50.0
MAX_LIMIT =                     200.0
FERROR = 0.050
MIN_FERROR = 0.010
HOME_OFFSET =                    0.0
HOME =                           100
HOME_SEARCH_VEL =                200.0
HOME_LATCH_VEL =                 20.0
HOME_USE_INDEX =                 NO
HOME_IGNORE_LIMITS =             NO
HOME_SEQUENCE = 1
HOME_IS_SHARED = 1

# Third axis
[AXIS_Z]
MIN_LIMIT = -75.0
MAX_LIMIT = 1000.0
MAX_VELOCITY = 166
MAX_ACCELERATION = 1500.0

[JOINT_1]
TYPE =                          LINEAR
MAX_VELOCITY =                  166
MAX_ACCELERATION =              1500.0
BACKLASH = 0.000
INPUT_SCALE =                   4000
OUTPUT_SCALE = 1.000
MIN_LIMIT =                     -75.0
MAX_LIMIT =                     1000.0
FERROR = 0.050
MIN_FERROR = 0.010
HOME_OFFSET =                    1.0
HOME =                           250
HOME_SEARCH_VEL =                200.0
HOME_LATCH_VEL =                 20.0
HOME_USE_INDEX =                 NO
HOME_IGNORE_LIMITS =             NO
HOME_SEQUENCE = 0
HOME_IS_SHARED = 1

# section for main IO controller parameters -----------------------------------
[MACROS]
MACRO = thread major pitch start-z end-z
MACRO = external final z

#INCLUDE layout2.inc

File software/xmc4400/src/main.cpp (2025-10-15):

/*
    PQ23,
	30.5mH, 7.5 Ohm @ 400Hz u->v, w open
	23.0mH, 5.2 Ohm @ 400Hz u->v+w

    FIXME:
	Allow a default state for digout when lock is lost.
*/
#include "vadc.h"

#include <atomic>
#include <complex>

constexpr float pi=acos(-1);

#include "hardware.h"
#include "ethernet.h"
#include "icmp.h"
#include "ccux.h"
#include "udp_struct.h"
#include "udp_sync.h"
#include "bitfields.h"
#include "encoder.h"
#include <arpa/inet.h>

#include "bsl.h"
using namespace std::complex_literals;
using namespace std::chrono_literals;
using std::sqrt;
using std::cos;
using std::sin;
using std::abs;
using C=std::complex<float>;

std::tuple hr_out{
    hrpwm0::half_bridge(HBH0_HR,HBL0_HR),
    hrpwm0::half_bridge(HBH1_HR,HBL1_HR),
    hrpwm0::half_bridge(HBH2_HR,HBL2_HR)
};

uart::full_duplex copro(COPRO_TXD,COPRO_RXD);
volatile bool copro_working=false;
int copro_not_working=0;

std::atomic<uint32_t> sleep_counter(0);

icmpProcessing icmp;

Ethernet eth0;

udp_sync syncer __attribute__((section ("ETH_RAM")));
udp_struct<motion_ns::to_drive,motion_ns::to_host> drive_io
    __attribute__((section ("ETH_RAM")));
udp_struct<config_ns::to_drive,config_ns::to_host> drive_config
    __attribute__((section ("ETH_RAM")));

std::array<int16_t,16> rx_data;
C Iset;

constexpr float current_scale=27.5/2048;

constexpr std::array<C,3> clarke{
    1.0f,
    -0.5f+0.5if*sqrt(3.0f),
    -0.5f-0.5if*sqrt(3.0f)
};

inline auto space_vector_mapping(C Vstator)
{
    std::array<float,3> out;

    if( (out[0]=imag(-clarke[2]*Vstator))>=0 &&
	(out[1]=imag( clarke[0]*Vstator))>=0
    ) {
	out[2]=0;
    } else if(
	(out[1]=imag(-clarke[1]*Vstator))>=0 &&
	(out[2]=imag( clarke[2]*Vstator))>=0
    ) {
	out[0]=0;
    } else {
	out[0]=imag( clarke[1]*Vstator);
	out[1]=0;
	out[2]=imag(-clarke[0]*Vstator);
    }
    return std::tuple_cat(out);
}

class complex_PI {
    C limit=0;
    C integrator;
    float P=0.2;
    float I=5e-3;
    float L=1;
public:

    C compute(C error,float voltage) {
	if(voltage<=10.0f) {
	    integrator=0;
	    return 0;
	}
	auto result=(P*error+integrator)/voltage;
	integrator+=I*error;

	C limited{
	    abs(real(result))>real(limit)?
		std::copysign(real(limit),real(result)): real(result),
	    abs(imag(result))>imag(limit)?
		std::copysign(imag(limit),imag(result)): imag(result)
	};

	if(result!=limited) {
	    auto correction=limited-result;
	    integrator+=correction*L;
	}
	return limited;
    }

    void set_limit(C l) { limit=l; }
    void set_gain(float p, float i, float l) { P=p; I=i; L=l; }
    void reset() { integrator=0; }
};

complex_PI Kcurrent;

static volatile int subsample;

motion_ns::to_host report;
C override=0;
C limit{0.44, 0.8};
float angle_offset=0;
float angle_override=0;

std::atomic<int> spinlock;
class locker_t {
    bool result;
    std::atomic<int> *p;
public:
    locker_t(std::atomic<int> &lock) {
	int expected=0;
	result=lock.compare_exchange_weak(expected,1);
	p=&lock;
    }
    ~locker_t() { (*p)=0; }

    operator bool() { return result; }
};

float sync_Kp=4e-3;
float sync_Ki=5e-6;

constexpr float scale_Vservo=(9900.0+27)/27/4096*3.3;

extern "C" void CCU43_1_IRQHandler()
{

    return;
}

bool locked;
bool enable;
extern "C" void CCU80_2_IRQHandler(void)
{
    static_assert(std::get<0>(hr_out).UNIT==0, "Wrong interrupt handler");
    static uint8_t trace_info;
    static bool overcurrent_latch=false;

    constexpr char data=0x05a;
    if(copro_working)
	copro.tx(data);
    itm.PORT[0].u8=trace_info=subsample;
    if(subsample==1) {
	auto t=syncer.sync(&eth0,50ns,sync_Kp,sync_Ki,20us);
	if(t!=0s) {
	    std::apply([=](auto ...x) { (x.period(t+pwm_time),...);}, hr_out);
	}
	report.timer_delta=t/1ns;
	report.timer_error=syncer.last_error()/1ns;
	encoder->trigger();
	itm.PORT[0].u8=(trace_info|=0x40);
    }
    if(++subsample>3)
	subsample=0;

    FCE_KE2->CFG=0;
    FCE_KE2->CRC=0xffff;
    uint16_t d;
    if(copro_working) {
	for(int rxd_counter=0; copro->TRBSR & USIC_CH_TRBSR_RBFLVL_Msk;) {
	    d>>=8;
	    d|=copro->OUTR<<8;
	    report.rx_data[rxd_counter/2]=rx_data[rxd_counter/2]=d;
	    rxd_counter++;
	    if(!(rxd_counter&1)) {
		FCE_KE2->IR=std::byteswap(d);
	    }
	    report.rx_counter=rxd_counter;
	}
	if(report.rx_counter!=12 && ++copro_not_working>10)
	    copro_working=0;
    } else
	copro_not_working=0;

    float Vservo=rx_data[2]*scale_Vservo+1e-6;

    RELAY0=drive_io->digout&1;
    RELAY1=drive_io->digout&2;
    enable=drive_io->digout&drive_io->DRIVE_ENABLE;
    overcurrent_latch&=enable;
    bool overvoltage=Vservo>drive_config->overvoltage;
    enable&=!overcurrent_latch && !overvoltage;

    C setpoint=0;
    locked=syncer.locked(&eth0) && drive_io.age(&eth0)<2ms;
    if(drive_io.age(&eth0)<0ms)
	drive_io.clear_timestamp();
    else if(locked && enable) {
	setpoint=drive_io->Iset[0]+1if*drive_io->Iset[1];
	ccu8::clear_trap(hr_out);	// enable outputs
	Kcurrent.set_limit(drive_io->limit[0]+1.0if*drive_io->limit[1]);
    } else if(abs(override)!=0.0f) {
	setpoint=override;
	ccu8::clear_trap(hr_out);	// enable outputs
	Kcurrent.set_limit(limit);
    } else {
	ccu8::set_trap(hr_out);	// disable outputs
	Kcurrent.set_limit(0.0f);
	Kcurrent.reset();
    }

    rx_data[0]-=2047;
    rx_data[1]-=2047;
    rx_data[3]-=2047;

    auto [position, angle]=encoder->get_position_angle();
    angle+=angle_offset;
    if(angle_override!=0.0f)
	angle=angle_override;
    IO0=report.position==position;
    report.position=position;
    report.index=encoder->index();
    report.angle=angle;
    report.encoder_missing=encoder->get_missing();
    report.encoder_invalid=encoder->get_invalid();
    itm.PORT[3].u32=report.encoder_missing;

    auto Istator=current_scale*(
	    clarke[0]*float(rx_data[0])+
	    clarke[1]*float(rx_data[1])+
	    clarke[2]*float(rx_data[3]));
    overcurrent_latch|=abs(Istator)>drive_config->overcurrent;
    IO7=overcurrent_latch;
    auto rotate=std::polar(1.0f, angle);
    auto Irotor=rotate*Istator;
    auto Vrotor=Kcurrent.compute(setpoint-Irotor, Vservo);
    auto Vstator=conj(rotate)*Vrotor;
    hr_out=space_vector_mapping(Vstator);

    if constexpr(0) {	// average for reporting
	static C Iavg[4], Irot;
	static int Iavg_counter=0;
	Irot-=Iavg[Iavg_counter];
	Iavg[Iavg_counter]=Irotor;
	Irot+=Iavg[Iavg_counter];
	if(++Iavg_counter>3)
	    Iavg_counter=0;
	Irotor=0.25f*Irot;
    }

    report.Irotor[0]=real(Irotor);
    report.Irotor[1]=imag(Irotor);
    report.Vrotor[0]=real(Vrotor);
    report.Vrotor[1]=imag(Vrotor);
    report.Vservo=Vservo;
    report.position2=glass_scale.count();
    report.index2=glass_scale.index();
    report.tpower=(0xffff&adc::vadc.G[1].RES[1]);
    report.offset=(0xffff&adc::vadc.G[0].RES[1]);
    report.ADC[0]=(0xffff&adc::vadc.G[0].RES[0])-report.offset;
    report.ADC[1]=(0xffff&adc::vadc.G[1].RES[0])-report.offset;
    report.digin=IO1 | (IO2<<1)
	| (encoder->get_age()<<2)
	| (enable? drive_io->DRIVE_ENABLE:0)
	| (overvoltage? drive_io->OVERVOLTAGE:0)
	| (overcurrent_latch? drive_io->OVERCURRENT:0);
    if(locked && subsample==0) {
	itm.PORT[0].u8=(trace_info|=0x80);
	static int32_t old_pos;
	IO3=old_pos==report.position;
	drive_io->new_data=0;
	drive_io.transmit(&eth0,report);
	report.counter++;
	old_pos=report.position;
    } else {
	if(drive_io.age(&eth0)>10ms)
	    drive_io->Iset[0]=drive_io->Iset[1]=0;
    }

    std::apply(ccu8::shadow_transfer,hr_out);
}

extern "C" void VADC0_G0_0_IRQHandler(void)
{
    LED3=0;
    vadc.G[0].REFCLR=vadc.G[0].REFLAG;
    LED3=1;
}

/* Need to modify startup_XMC... for this to work,
    replace "b ." to "b DefaultHandler"
*/
extern "C" void Default_Handler(void)
{
    itm.PORT[0].u32=SCB->SHCSR;
    itm.PORT[1].u32=SCB->CFSR;
    itm.PORT[1].u32=SCB->BFAR;
    uint32_t addr;
    asm volatile (
	"ldr.w %0,[sp,0x18];"	// Return address
	: "=r"(addr)
    );
    ccu8::set_trap(hr_out);	// disable outputs
    itm.PORT[0].u32=addr;
    for(uint8_t i=0;i<10;i++)
	itm.PORT[0].u8=i; // make sure the frame on the traceport is finished
    for(;;);
}

volatile uint32_t counter, led, txd=-1, hrpwm_status;
volatile int init_enable=0;

auto fan_timer=hrpwm0::center_aligned(FAN);

inline void start_copro()
{
    bsl_init(COPRO_POWER,COPRO_TXD,COPRO_RXD);
    copro.SetBaudrate(uart::Baudrate(4e6));
    uart::fifo_configure<0,16>(copro);
    copro_working=true;
    copro->BYPCR=USIC_CH_BYPCR_BDVTR_Msk |
	bitfield<USIC_CH_BYPCR_BDEN_Msk>(2) |
	bitfield<USIC_CH_BYPCR_BWLE_Msk>(8);
    copro->TBUF[0]=0x05a;
}

void init_adc(void);
volatile int trap_enable=0;
int main()
{
    SystemCoreClockUpdate();
    ETH_RESET=1; ETH_RESET.set(XMC_GPIO_MODE_OUTPUT_PUSH_PULL);
    ENC_5V=0; ENC_5V.set(XMC_GPIO_MODE_OUTPUT_PUSH_PULL);
    ENC_12V=0; ENC_12V.set(XMC_GPIO_MODE_OUTPUT_PUSH_PULL);
    ENC_DIR=0; ENC_DIR.set(XMC_GPIO_MODE_OUTPUT_PUSH_PULL);
    IO7=0; IO7.set(XMC_GPIO_MODE_OUTPUT_PUSH_PULL);
    IO0=0; IO0.set(XMC_GPIO_MODE_OUTPUT_PUSH_PULL);
    IO1.set(XMC_GPIO_MODE_INPUT_PULL_UP);
    IO2.set(XMC_GPIO_MODE_INPUT_PULL_UP);
    RELAY0=0; RELAY0.set(XMC_GPIO_MODE_OUTPUT_PUSH_PULL);
    RELAY1=0; RELAY1.set(XMC_GPIO_MODE_OUTPUT_PUSH_PULL);
    IO3=0; IO3.set(XMC_GPIO_MODE_OUTPUT_PUSH_PULL);
    COPRO_POWER=0; COPRO_POWER.set(XMC_GPIO_MODE_OUTPUT_PUSH_PULL);
    ENC_DDIR=0; ENC_DDIR.set(XMC_GPIO_MODE_OUTPUT_PUSH_PULL);
    ENC_CDIR=0; ENC_CDIR.set(XMC_GPIO_MODE_OUTPUT_PUSH_PULL);
    SUPPLY_VOLTAGE=1; SUPPLY_VOLTAGE.set(XMC_GPIO_MODE_OUTPUT_PUSH_PULL);

    // Turn traceport on.
    TRACECLK.set(XMC_GPIO_HWCTRL_PERIPHERAL1);
    TRACECLK.set(XMC_GPIO_OUTPUT_STRENGTH_STRONG_MEDIUM_EDGE);
    LED0.set(XMC_GPIO_HWCTRL_PERIPHERAL1);
    LED0.set(XMC_GPIO_OUTPUT_STRENGTH_STRONG_MEDIUM_EDGE);
    LED1.set(XMC_GPIO_HWCTRL_PERIPHERAL1);
    LED1.set(XMC_GPIO_OUTPUT_STRENGTH_STRONG_MEDIUM_EDGE);
    LED2.set(XMC_GPIO_HWCTRL_PERIPHERAL1);
    LED2.set(XMC_GPIO_OUTPUT_STRENGTH_STRONG_MEDIUM_EDGE);
    LED3.set(XMC_GPIO_HWCTRL_PERIPHERAL1);
    LED3.set(XMC_GPIO_OUTPUT_STRENGTH_STRONG_MEDIUM_EDGE);
    tpi.CSPSR=8;
    tpi.SPPR=0;
    tpi.FFCR=0;
    dwt.CTRL=0x40010001;
    itm.LAR=0xC5ACCE55;
    itm.TCR=0x0001000d;
    itm.TER=0xffffffff;

    TRACESWO.set(XMC_GPIO_HWCTRL_DISABLED);

    eth0.init( // Hangt zonder ethernet kabel
	0,
	RXD0, RXD1, CLK_RMII, CRS_DV, RXER, TXD0, TXD1, TX_EN, MDC, MDIO,
	&icmp
    );
    /*
    eth0.add_udp_receiver(&poker,ntohs(2));
    */
    syncer.TimestampInit();
    eth0.add_udp_receiver(&drive_io,ntohs(motion_ns::port));
    eth0.add_udp_receiver(&syncer,ntohs(sync_ns::port));
    eth0.add_udp_receiver(&drive_config,ntohs(config_ns::port));

    FCE->CLC=0; // Enable CRC engine

    SysTick_Config(1000000);
    SysTick->CTRL&=~SysTick_CTRL_TICKINT_Msk;
    NVIC_DisableIRQ(SysTick_IRQn);

    start_copro();

    HBH0_HR.set(XMC_GPIO_OUTPUT_STRENGTH_STRONG_SHARP_EDGE);
    HBL0_HR.set(XMC_GPIO_OUTPUT_STRENGTH_STRONG_SHARP_EDGE);

    ccu8::init<0>(
	XMC_CCU8_CLOCK_SCU,
	XMC_CCU8_SLICE_MCMS_ACTION_TRANSFER_PR_CR
    );
    hrpwm_status=hrpwm0::init();

    std::apply([](auto& ... hr) {
	(hr.init(1,1), ...);
	(hr.period(pwm_time), ...);
	(hr.deadtime(100ns, 100ns), ...);
	(hr.shadow_transfer_mode(ccu8::TRANSFER_PERIOD), ...);
	(hr.enable_trap(), ...);
	((hr=0.25f), ...);
    }, hr_out);

    {
	auto &c=std::get<0>(hr_out)->ccu8;
	c->INTE=CCU8_CC8_INTE_CMU2E_Msk;
	c->SRS=bitfield<CCU8_CC8_SRS_CM2SR_Msk>(2);
	c->CR2S=c->PRS-200;
	NVIC_SetPriority(c.irq<2>(), 1);
	NVIC_EnableIRQ(c.irq<2>());
    }

    std::apply(ccu8::shadow_transfer,hr_out);
    std::apply(ccux::start,hr_out);

    ////////////////////////////////////////////////////////////////////////////
    // ADC
    ////////////////////////////////////////////////////////////////////////////
    adc::init();
    adc::global_class<0>(XMC_VADC_CONVMODE_12BIT,8);
    adc::channel_control<0>(ENC_COS,   XMC_VADC_CHANNEL_CONV_GLOBAL_CLASS0, 0);
    adc::channel_control<0>(AN_IN5,    XMC_VADC_CHANNEL_CONV_GLOBAL_CLASS0, 1);
    adc::channel_control<1>(ENC_SIN_A, XMC_VADC_CHANNEL_CONV_GLOBAL_CLASS0, 0);
    adc::channel_control<1>(TPOWER,    XMC_VADC_CHANNEL_CONV_GLOBAL_CLASS0, 1);
    adc::queue_config<0>( XMC_VADC_GATEMODE_IGNORE, 0,
	XMC_VADC_REQ_TR_CCU80_SR2, XMC_VADC_TRIGGER_EDGE_RISING
    );
    adc::queue_config<1>( XMC_VADC_GATEMODE_IGNORE, 0,
	XMC_VADC_REQ_TR_CCU80_SR2, XMC_VADC_TRIGGER_EDGE_RISING
    );

    for(int i: {0,1}) {
	adc::vadc.G[i].ARBPR=
	    bitfield<VADC_G_ARBPR_PRIO0_Msk>(3) |
	    VADC_G_ARBPR_CSM0_Msk |
	    VADC_G_ARBPR_ASEN0_Msk;
	adc::vadc.G[i].ARBCFG=
	    bitfield<VADC_G_ARBCFG_ANONC_Msk>(3) |
	    bitfield<VADC_G_ARBCFG_ANONS_Msk>(3);
    }
    adc::queue<0>(ENC_COS, adc::EXTERNAL_TRIGGER| adc::REFILL);
    adc::queue<0>(AN_IN5, adc::REFILL);
    adc::queue<1>(ENC_SIN_A, adc::EXTERNAL_TRIGGER| adc::REFILL);
    adc::queue<1>(TPOWER, adc::REFILL);
    ////////////////////////////////////////////////////////////////////////////

    init_encoder();

    std::atomic_thread_fence(std::memory_order_release);

    fan_timer.init();
    fan_timer.period(100us);
    fan_timer=0.5f;
    ccu8::start(fan_timer);
    ccu8::shadow_transfer(fan_timer);

    //eru::dev1.EXISEL

    auto old_led=led;
    for(;;) {
	//asm volatile ("WFI");
	if(led!=old_led) {
	    old_led=led;
	    LED0=old_led&1;
	    LED1=(old_led>>1)&1;
	    LED2=(old_led>>2)&1;
	    LED3=(old_led>>3)&1;
	}
	counter++;
	std::apply([](auto& ... hr) {
	    if(trap_enable&1)
		(hr.disable_trap(), ...);
	    if(trap_enable&2)
		(hr.enable_trap(), ...);
	    if(trap_enable&4)
		(hr.set_trap(), ...);
	    if(trap_enable&8)
		(hr.clear_trap(), ...);
	}, hr_out);
	if(drive_config->new_data) {
	    led=drive_config->led;
	    Kcurrent.set_gain(drive_config->current_P, drive_config->current_I,
		drive_config->current_L);
	    if(drive_config->encoder&0x40000000)
		glass_scale.negative_index();
	    else
		glass_scale.positive_index();
	    angle_offset=drive_config->angle_offset;
	    drive_config->new_data=0;
	    drive_config.transmit(&eth0,config_ns::to_host{});
	}
	if(drive_config->encoder) {
	    locker_t change_encoder(spinlock);
	    if(change_encoder) {
		set_encoder(drive_config->encoder, drive_config->poles);
		drive_config->encoder=0;
	    }
	}
	if(!copro_working)
	    start_copro();
    }
    return 0;
}


/* This removes a lot of code from the binary
*/
void __gnu_cxx::__verbose_terminate_handler(void)
{
    LED0.set(XMC_GPIO_MODE_OUTPUT_PUSH_PULL);
    LED1.set(XMC_GPIO_MODE_OUTPUT_PUSH_PULL);
    LED2.set(XMC_GPIO_MODE_OUTPUT_PUSH_PULL);
    LED3.set(XMC_GPIO_MODE_OUTPUT_PUSH_PULL);
    for(;;) {
	LED0^=1;
	LED1^=1;
	LED2^=1;
    }
}

void debug() {}

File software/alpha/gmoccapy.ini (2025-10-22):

[EMC]
	VERSION = 1.1
	MACHINE = HARRISON_ALPHA_330
	DEBUG = 0

[DISPLAY]
	DISPLAY = gmoccapy
	PYVCP = lathe.xml
	LATHE = 1
	CYCLE_TIME = 100
	POSITION_OFFSET = RELATIVE
	POSITION_FEEDBACK = ACTUAL
	MAX_FEED_OVERRIDE = 1.2
	MAX_SPINDLE_OVERRIDE = 1.0
	PROGRAM_PREFIX = /home/mark/nc_files/
	EMBED_TAB_NAME = Spindle_load
	EMBED_TAB_LOCATION = box_custom_4
	EMBED_TAB_COMMAND = gladevcp -x {XID} -H spindle_load.hal spindle_load.glade 
	EMBED_TAB_NAME = Drive_status
	EMBED_TAB_LOCATION = hbox_jog
	EMBED_TAB_COMMAND = gladevcp -x {XID} -H drive_status.hal drive_status.glade
	LINEAR_INCREMENTS = 1.000 mm, 0.100 mm, 0.010 mm, 0.001 mm
	MIN_LINEAR_VELOCITY = 0
	MAX_LINEAR_VELOCITY = 50
	DEFAULT_SPINDLE_0_SPEED = 200
	MIN_SPINDLE_0_SPEED = 20
	MAX_SPINDLE_0_SPEED = 1700
	MIN_SPINDLE_0_OVERRIDE = 0.5
	MAX_SPINDLE_0_OVERRIDE = 1.2
	MIN_ANGULAR_VELOCITY = 0.1
	DEFAULT_ANGULAR_VELOCITY = 360
	MAX_ANGULAR_VELOCITY =  3600
	DEFAULT_SPINDLE_SPEED = 300
	MIN_SPINDLE_OVERRIDE = 0.5
	DEFAULT_LINEAR_VELOCITY = 25
	INCREMENTS=0.001mm 0.01mm 0.1mm


[HAL]
	HALUI = halui
        HALFILE = ./lathe_cmds.hal
        HALFILE = gmoccapy.hal
        POSTGUI_HALFILE = gmoccapy_postgui.hal



#INCLUDE base.inc
#INCLUDE layout2.inc

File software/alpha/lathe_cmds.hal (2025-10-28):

# Wed Dec 13 23:32:01 CET 2023
#
# This file:    ./lathe_cmds.hal
# Created by:   /usr/src/linuxcnc/lib/hallib/basic_sim.tcl
# With options: 
# From inifile: /home/mark/kicad/motor_sturing/software/lathe/lathe.ini
# Halfiles:     LIB:basic_sim.tcl
#
# This file contains the hal commands produced by basic_sim.tcl
# (and any hal commands executed prior to its execution).
# ------------------------------------------------------------------
# To use ./lathe_cmds.hal in the original inifile (or a copy of it),
# edit to change:
#     [HAL]
#     HALFILE = LIB:basic_sim.tcl parameters
# to:
#     [HAL]
#     HALFILE = ./lathe_cmds.hal
#
# Notes:
#  1) Inifile Variables substitutions specified in the inifile
#     and interpreted by halcmd are automatically substituted
#     in the created halfile (./lathe_cmds.hal).
#  2) Input pins connected to a signal with no writer are
#     not included in the setp listings herein so must be added
#     manually
#

# user space components
loadusr -W hal_manualtoolchange

# components
#preloaded module: loadrt tpmod 
#preloaded module: loadrt homemod 
loadrt trivkins coordinates=xz 
loadrt motmod base_period_nsec=222222 servo_period_nsec=222222 num_joints=2 
loadrt etherdrive device=eth1 names=c2:00:93:15:0d:00,c2:80:12:1c:0d:00
loadrt statespace_3 count=2
loadrt absolute_index count=2

# pin aliases
# param aliases
# signals
# nets
net estop:loop iocontrol.0.user-enable-out => iocontrol.0.emc-enable-in
net tool:change iocontrol.0.tool-change => hal_manualtoolchange.change
net tool:changed hal_manualtoolchange.changed => iocontrol.0.tool-changed
net tool:prep-loop iocontrol.0.tool-prepare => iocontrol.0.tool-prepared
net tool:prep-number iocontrol.0.tool-prep-number => hal_manualtoolchange.number

# parameter values
setp motion-command-handler.tmax    0
setp motion-controller.tmax         0
setp servo-thread.tmax              0

##################
# Control loops
##################
#
# X
#
# scale is used to convert from encoder units to mm. mm=encoder/scale
#
setp absolute_index.0.counts_per_index	65536
setp absolute_index.0.scale		-21845.333333333333
setp statespace_3.0.scale-0		-21845.333333333333
setp statespace_3.0.scale-1		1
setp statespace_3.0.A-0-0		0.0000000000e+00
setp statespace_3.0.A-0-1		0.0000000000e+00
setp statespace_3.0.A-0-2		-7.2145650766e-03
setp statespace_3.0.A-1-0		1.0000000000e+00
setp statespace_3.0.A-1-1		0.0000000000e+00
setp statespace_3.0.A-1-2		6.0934449948e-02
setp statespace_3.0.A-2-0		0.0000000000e+00
setp statespace_3.0.A-2-1		-1.0000000000e+01
setp statespace_3.0.A-2-2		1.5371988487e+00
setp statespace_3.0.B-0-0		-2.0922073275e-05
setp statespace_3.0.B-0-1		0.0000000000e+00
setp statespace_3.0.B-1-0		-8.5839745839e-05
setp statespace_3.0.B-1-1		0.0000000000e+00
setp statespace_3.0.B-2-0		-1.0616322548e-03
setp statespace_3.0.B-2-1		0.0000000000e+00
setp statespace_3.0.C-0-0		0.0000000000e+00
setp statespace_3.0.C-0-1		0.0000000000e+00
setp statespace_3.0.C-0-2		-1.0000000000e+02
setp statespace_3.0.D-0-0		-2.8999770676e-01
setp statespace_3.0.D-0-1		0.0000000000e+00
setp statespace_3.0.K-0-0		-1.6470556386e-04
setp statespace_3.0.K-1-0		5.3908674005e-04
setp statespace_3.0.K-2-0		3.1895139001e-03
setp statespace_3.0.limit-0		6.5

setp etherdrive.0.angle_offset		0
setp etherdrive.0.limit-0		0.44
setp etherdrive.0.limit-1		0.7
setp etherdrive.0.P			16
setp etherdrive.0.I			0.2
setp etherdrive.0.L			1
setp etherdrive.0.overvoltage		160
setp etherdrive.0.overcurrent		7
setp etherdrive.0.encoder		0

#
# Z
#
setp absolute_index.1.counts_per_index	65536
setp absolute_index.1.scale		-32768
setp statespace_3.1.scale-0		-32768
setp statespace_3.1.scale-1		1
setp statespace_3.1.A-0-0		0.0000000000e+00
setp statespace_3.1.A-0-1		0.0000000000e+00
setp statespace_3.1.A-0-2		-2.8200014652e-02
setp statespace_3.1.A-1-0		-1.0000000000e+00
setp statespace_3.1.A-1-1		0.0000000000e+00
setp statespace_3.1.A-1-2		-1.3440738662e-01
setp statespace_3.1.A-2-0		0.0000000000e+00
setp statespace_3.1.A-2-1		1.0000000000e+01
setp statespace_3.1.A-2-2		2.0620737197e+00
setp statespace_3.1.B-0-0		2.9084105097e-04
setp statespace_3.1.B-0-1		0.0000000000e+00
setp statespace_3.1.B-1-0		3.9873977912e-04
setp statespace_3.1.B-1-1		0.0000000000e+00
setp statespace_3.1.B-2-0		-1.0836108432e-03
setp statespace_3.1.B-2-1		0.0000000000e+00
setp statespace_3.1.C-0-0		0.0000000000e+00
setp statespace_3.1.C-0-1		0.0000000000e+00
setp statespace_3.1.C-0-2		1.0000000000e+01
setp statespace_3.1.D-0-0		-1.0313507087e-01
setp statespace_3.1.D-0-1		0.0000000000e+00
setp statespace_3.1.K-0-0		-2.6983626313e-03
setp statespace_3.1.K-1-0		-1.1854009756e-02
setp statespace_3.1.K-2-0		1.3721326716e-01
setp statespace_3.1.limit-0		6.5

setp etherdrive.1.angle_offset		0
setp etherdrive.1.limit-0		0.44
setp etherdrive.1.limit-1		0.7
setp etherdrive.1.P			16
setp etherdrive.1.I			0.2
setp etherdrive.1.L			1
setp etherdrive.1.overvoltage		160
setp etherdrive.1.overcurrent		7
setp etherdrive.1.encoder		0

# realtime thread/function links
addf etherdrive.sync servo-thread
addf absolute_index.compute servo-thread
addf statespace_3.compute servo-thread
addf etherdrive.send servo-thread
addf motion-command-handler servo-thread
addf motion-controller servo-thread

#
#
net J0:pos-cmd joint.0.motor-pos-cmd  	=> statespace_3.0.setpoint
net J0:pos-dro statespace_3.0.position-0 => joint.0.motor-pos-fb
net J0:Iset statespace_3.0.out 	=> etherdrive.0.Iset-1
net J0:enable joint.0.amp-enable-out 	=> etherdrive.0.enable statespace_3.0.enable absolute_index.0.enable
net J0:index etherdrive.0.index	=> absolute_index.0.index
net J0:pos-drive etherdrive.0.position => absolute_index.0.position-in
net J0:pos-index absolute_index.0.position-out => statespace_3.0.in-0
net J0:pos-joint joint.0.pos-fb => absolute_index.0.pos-fb
net J0:home absolute_index.0.home => halui.joint.0.home
net J0:is-homed halui.joint.0.is-homed => absolute_index.0.is-homed

net J1:pos-cmd joint.1.motor-pos-cmd	=> statespace_3.1.setpoint
net J1:pos-dro statespace_3.1.position-0 => joint.1.motor-pos-fb
net J1:Iset statespace_3.1.out	=> etherdrive.1.Iset-1
net J1:enable joint.1.amp-enable-out	=> etherdrive.1.enable statespace_3.1.enable absolute_index.1.enable
net J1:index etherdrive.1.index	=> absolute_index.1.index
net J1:pos-drive etherdrive.1.position => absolute_index.1.position-in
net J1:pos-index absolute_index.1.position-out => statespace_3.1.in-0
net J1:pos-joint joint.1.pos-fb => absolute_index.1.pos-fb
net J1:home absolute_index.1.home => halui.joint.1.home
net J1:is-homed halui.joint.1.is-homed => absolute_index.1.is-homed

net coolant iocontrol.0.coolant-mist => etherdrive.0.digout-0 etherdrive.0.digout-1 

loadrt logic count=1 personality=0x1203
addf logic.0 servo-thread
net unconfigured-0 etherdrive.0.unconfigured => logic.0.in-00 halui.joint.0.unhome
net unconfigured-1 etherdrive.1.unconfigured => logic.0.in-01 halui.joint.1.unhome
net estop-on  logic.0.or => halui.estop.activate
net estop-off logic.0.nor => halui.estop.reset

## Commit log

2016-02-22 Before moving to SiC fets.
    [drive.sch, fpga.sch, motor_sturing.kicad_pcb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]
2016-03-03 Backup, clearing bottom of power section.
    [drive.sch, fpga.sch, motor_sturing.kicad_pcb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]
2016-07-10 First small drive hardware.
    [drive.sch, g_sensorsch.sch, motor_sturing.kicad_pcb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]
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2016-07-20 Encoder TXD matched with mitsubishi drive.
    [small_drive.sch]
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2016-07-25 Oops wrong sign for phase->orth current.
    [small_drive.sch]
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2016-08-21 Doesn't work. Clocks?
    [small_drive.sch]
2016-08-21 Now the checksum is also correct.
    [main.cpp]
2016-09-17 Header conversion in C++
    [small_drive.kicad_pcb, small_drive.sch]
2016-09-18 Should work but doesn't enter main
    [main.cpp]
2016-09-20 Initial test on XMC4400, LED0/mdc/mdio works.
    [small_drive.sch]
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2016-09-28 Can receive packets on the xmc4400, ping does not work yet.
    [main.cpp]
2016-09-30 PWM (low resolution) works.
    [small_drive.sch]
2016-09-30 Functional PWM, including subsampling interrupt.
    [small_drive.kicad_pcb, small_drive.sch]
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2016-10-18 Working logger on board.
    [small_drive.sch]
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2016-12-18 Solved a very tight timing issue.
    [encoder.cpp, main.cpp]
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2016-12-24 DSD works for the AMC1204.
    [small_drive.kicad_pcb, small_drive.sch]
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2017-01-14 Adding timestamp. Fixed port numbers.
    [small_drive.sch]
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2017-01-22 Added interrupt handler for shadow register transfer.
    This was necessary because the control loop might take longer which
    caused the interval between updates of the slow and the fast slices to
    get out of sync. For some reason setting STC.stm=1 does not work.
    [main.cpp]
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2017-01-31 Add encoder value for hiperface. Timer concatenation does not work.
    [encoder.cpp, main.cpp]
2017-02-03 Hiperface interpolation (needs hardware patches)
    [small_drive.sch]
2017-02-03 Convert etherdrive to C++
    [etherdrive.hal, lathe_servo.hal]
2017-02-04 Reduce jitter on drive PWM.
    Note: this requires linuxcnc to be modified.
    [etherdrive.cpp, lathe.ini]
2017-02-04 Fixed receiver overflow for the PQ23 motor.
    [encoder.cpp, main.cpp]
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2017-02-05 Prevent Ethernet MMC interrupts.
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2017-02-06 Fix mitsubishi PQ23 encoder zero wrap.
    [encoder.cpp, main.cpp]
2017-02-17 Fully routed PCB with 100-pin package
    [small_drive.kicad_pcb, small_drive.sch]
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2017-03-01 New small_drive, untested, unverified.
    [small_drive.kicad_pcb, small_drive.sch]
2017-04-02 Adding more advanced speed observer model.
    [small_drive.kicad_pcb, small_drive.sch]
2017-04-02 Configuring the lathe, work in progress.
    [etherdrive.hal]
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2017-04-15 Fixing current ripple
2017-04-17 Use 5V for opamp supply.
    [small_drive.kicad_pcb, small_drive.sch]
2017-04-30 Velocity estimator, HB04, G71.
    [etherdrive.hal, velocity_estimator.hal]
2017-05-06 Made posif 32-bit in timer. Encoder fails when the drive is not yet synchronised.
    [encoder.cpp, main.cpp]
2017-05-06 Using capture for position and index for POSIF. Fixed occasional problem with half_duplex transmission.
    [encoder.cpp, main.cpp]
2017-05-06 Timing improved for half-duplex RS485
    [etherdrive.hal]
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2017-07-17 Use homing sensor fo Z.
    [homing.hal]
2017-07-19 Use printerport instead of USB relays.
    [homing.hal]
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2018-03-23 Working machine with new encoder on z-axis. (Needs tuning)
    [etherdrive.hal]
2019-01-02 Adding power_stage for high voltage drive.
    [h_bridge.sch, power_stage.kicad_pcb, power_stage.sch]
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2019-02-17 Starting the control_stage (copied from small_drive)
    [control_stage.kicad_pcb, control_stage.sch, homing.hal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]
2019-02-17 Control stage, initial version.
    [control_stage.kicad_pcb, control_stage.sch]
2021-01-03 Starting software on hv_drive
    [control_stage.kicad_pcb, control_stage.sch, flyback.kicad_sch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]
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2021-01-18 xmc1300 can toggle pin.
    [hv_control.kicad_sch]
2021-01-23 Restructure with XMCLib as submodule
    [etherdrive.hal, homing.hal, lathe_cmds.hal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]
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2021-01-31 Adding scripts to use the parallel trace port. Only 4-bit interface tested.
    [hv_control.kicad_sch]
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2022-01-10 Moving to new CCU8 implementation. Moved trace and @arm scripts to octave archive.
    [flyback.kicad_sch, h_bridge.kicad_sch, hv_control.kicad_sch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]
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2022-01-12 HRPWM0 pins are unique, so only require port and pin to identify.
    [hv_control.kicad_sch]
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2022-01-30 Using falling edge of start-bit on the XMC1300 to trigger the ADC. Routed using P0.9 and CCU40_CC3.
    [hv_control.kicad_sch]
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2022-02-09 MFS13 encoder using new uart driver.
    [flyback.kicad_sch, hv_control.kicad_sch]
2022-02-09 Remove glitches on half-duplex encoder data.
    [encoder.cpp]
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2022-02-14 Motor runs, encoder checksum does not work.
    [hv_power.kicad_pcb]
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2022-02-21 Adding startup_XMC4400.S to change DefaultHandler (this allows the traceport to identify the problem)
2023-01-30 Put pulses on the printerport. Latency was fixed with: ethtool -C eth2 rx-usecs 0
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2023-10-17 Extend AMT21 encoder to 21-bits. motion-test in two directions. Keep old position if encoder fails
    [encoder.cpp, main.cpp]
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2023-10-29 Update syncing gains. The old ones occasionally entered a non-linear oscillation.
    [main.cpp]
2023-11-08 Fix orientation/polarity of current/encoder/voltage. Modified for board v2 (COPRO_POWER)
    [encoder.cpp, hardware.h, main.cpp]
2023-11-10 Set the run bit in the timer for the POSIF.
    [hv_control.kicad_pcb, hv_control.kicad_sch, hv_power.kicad_pcb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]
2023-11-19 Add 2nd order state space controller. Use all three current measurements to reduce noise.
    [encoder.cpp, hardware.h, main.cpp]
2023-11-19 Remarks for next version.
    [flyback.kicad_sch, hv_control.kicad_sch]
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2023-12-03 Update encoder->ethernet timing. Improved gains. Removed position ripple by reducing misalignment of ball-screw.
    [main.cpp]
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2023-12-09 Update current test to allow sending a profile.
    [h_bridge.kicad_sch]
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2023-12-14 First noise from the drive.
    [lathe_cmds.hal]
2023-12-16 XZ move, lots of rattling (to much jitter on sync?)
    [lathe_cmds.hal]
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2023-12-18 Most of the motion control seems to work, timebase in linuxcnc is too unstable.
    [lathe_cmds.hal]
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2023-12-21 Trying to find out why we mis packets.
    [lathe_cmds.hal]
2023-12-22 This works, but there is still the occasional hiccup.
    [lathe_cmds.hal]
2023-12-22 Retune X after replacing the belt with a narrowwer version and loosen the bearings.
    TODO: Fix syncer lock detection.
    [lathe_cmds.hal]
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2024-01-03 Drives use DRIVE_ENABLE and data is updated before machine is turned on.
    [lathe_cmds.hal]
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2024-01-13 Allow for negated index pulse on linear encoder.
    [flyback.kicad_sch, hv_power.kicad_pcb]
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2024-01-13 Adding combined linuxcnc configuration directoty for axis and gmoccapy.
    [gmoccapy.hal, gmoccapy_postgui.hal, lathe_cmds.hal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]
2024-01-15 Fixed indexing for Sino scales.
    [lathe.ini, main.cpp]
2024-01-22 Re-tuned X. Attached spindle speed bar in gmoccapy.
    [gmoccapy_postgui.hal, lathe_cmds.hal]
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2024-01-27 Occasionally the z-axis fails. Retry programming the copro.
    [main.cpp]
2024-01-27 Allow S96 to work and removed some unused stuff. Speed_controller is not working properly.
    [lathe_cmds.hal]
2024-02-10 Retry if xmc1300 is not starting up properly.
    [lathe_cmds.hal]
2024-02-11 Much better speed controller. Not sure why the encoder occasionally misses.
    [lathe_cmds.hal]
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2024-07-21 Make speed_controller more robust. The CUI encoder is still repeating values.
    [lathe_cmds.hal]
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2024-07-28 This seems to fix the issue with the glass_scale not wanting to start decrementing until after an increment. The polarity of input A if flipped, and later flipped back. This way the encoder is counti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
    [main.cpp]
2024-08-18 Made startup of the XMC1300 more robust, requires a bleed resistor of 220 Ohm on the 3.3V of the XMC1300.
    [flyback.kicad_sch, hv_control.kicad_sch]
2024-09-01 Updated encoder statistics. Adding drive status page en manual mode.
    [drive_status.hal, gmoccapy_postgui.hal]
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2024-09-01 New panel (needs mod to gmoccapy for setup led)
    [gmoccapy.hal, gmoccapy_postgui.hal]
2024-09-09 Add PWM to the FAN output (wrong pin)
    [ccu4.h, hardware.h, main.cpp]
2024-09-09 Fan PWM on correct pin.
    [hardware.h, main.cpp]
2024-09-09 Fixed a lot of timer issues.
    [bsl.h, ccu4.h, main.cpp]
2024-10-27 Change timing of measurements.
    Add incremental pulse encoder.
    [hv_control.kicad_sch]
2024-11-04 Add missing h_bridge.sch
    [h_bridge.sch]
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2025-09-17 Add missing file
    [core_sim_lathe.hal]
2025-09-28 Receive Fanuc correctly, CRC not yet interpreted.
    [encoder.cpp, main.cpp, uart.h]
2025-10-03 Switch frame length ASAP, to make the the CRC is captured correctly. Removed debugging copy of Fanuc encoder message.
    [encoder.cpp, main.cpp]
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2025-10-05 Try to find and fix the occasional position error.
    [encoder.cpp]
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2025-10-06 Use crc_bits to clear the carry bit instead of a constant which only works on 5-bit CRCs. Fixed a typo in the comment.
    [encoder.cpp]
2025-10-15 Adding type3 compensation instead of PID. This should reduce noise.
    [encoder.cpp, main.cpp]
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2025-10-27 absolute_index seems to work from a cold and a warm start.
    Restarting the drives does not yet work.
    [lathe_cmds.hal]
2025-10-27 This also works at high speed while passing the index. Added z-axis.
    [lathe_cmds.hal]
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2025-10-28 Allow user to unhome the axis when overshooting the limits.
    [absolute_index.cpp]
